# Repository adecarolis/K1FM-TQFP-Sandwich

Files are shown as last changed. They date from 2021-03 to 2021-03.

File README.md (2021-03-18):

# TQFP Sandwich

## A fully open sourced drop-in replacement for the [DL2MAN Sandwich](https://dl2man.de/)

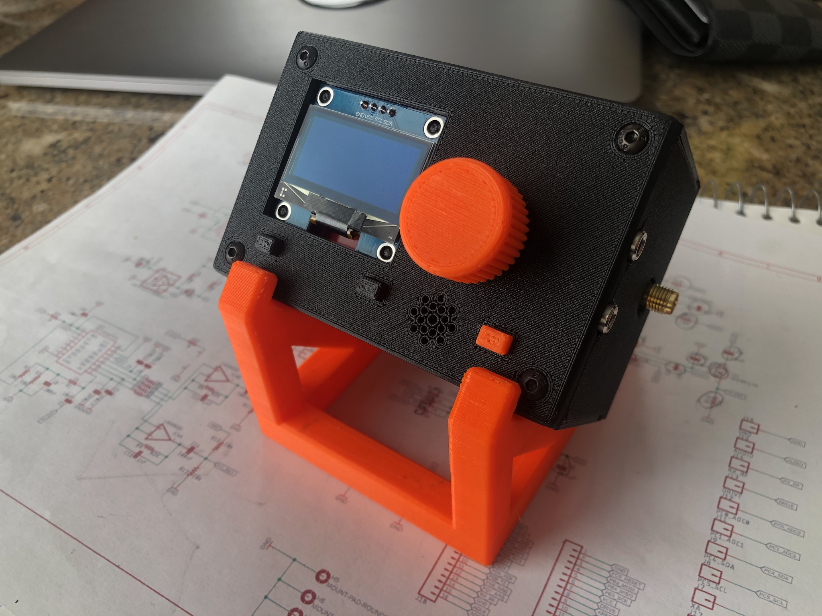
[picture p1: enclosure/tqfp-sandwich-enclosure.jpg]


This sligthly modified version of [Manuel DL2MAN](https://dl2man.de/)'s exceptional project was originally motivated by the need of a proper power connector and a TCXO. Subsequently an SWR meter and a 1.3" oled display were added.

### Boards

#### Main

- ATM328P on TQFP-32 footprint + all SMD components + single side, 2 layers design ($2 per 5 bare PCBs at JLCPCB)
- Available CPL and BOM files for rapid prototyping orders (~$39 for 5 fully assembled PCBs at JLCPCB ***)
- Round barrel jack connector compatible with the FT-817 (1.70mm ID - 4.00mm OD)
- Temperature Controlled Oscillator (TCXO) for absolute frequency precision (alignment no longer necessary)
- Extra 0 ohm resistors / contact pads for easier experimenting and troubleshooting

#### UI

- Accepts both 0.96" and 1.3" OLED displays
- Anti-bounce capacitors allowing for low-cost encoders being used
- Optional GPS receiver + antenna (not yet tested)
- Optional LM386 audio amplifier (not yet tested)

#### RF

- Compatible with DL2MAN REV3 standard RF boards
- Onboard SWR/Wattmeter
- High bands design: 10m, 15m, 20m, 30m, 40m
- SMD design allows for using either a single IRLML2060 or three MMBF170's (caps and toroids need to be matched accordingly)
- SMD Relays (Omron G6KU-2G-Y)

*** Parts not available (or currently not in stock) at LCSC that need to be sourced and installed separately: PJ-18H, Si5351, LM4562MAX, ASTX-H11-27.000MHZ-T, FST3253MTCX

### Testing

 This project is to be considered as experimental. If you are looking for stability and reliabiality, I'd recommend sticking to the original. 

| Board | Number built | Remarks | Issues |
| :---: | :---: | --- | --- |
| Main  | 4 | - No performance differences from the original found yet.<br />- Only tested with OLED displays. | |
|  UI | 5 | - Most 1.3" displays work normally but some require [a software patch](https://groups.io/g/ucx/message/5147?p=,,,20,0,0,0::Created,,reverted,20,2,0,79343439) (this would be the case for all UI boards, not just this particular one). | GPS and audio amplifier (both optional) not yet tested. |
|  RF | 1 | - Uses the REV3 IO Extender configuration with 3x SOT23 mosfets therefore passive components can be dimensioned after BS170/MMBF170's or IRLML2060's.<br />- [The SWR meter software](https://github.com/adecarolis/QCX-SSB/tree/swr-meter) modification currently only works for CW when using the straight key. | So far only tested on 20 meters and 40 meters using 3x BS170 mosfets: good performance on 20 meters, not good on 40. |

### License

Creative Commons 3.0

https://creativecommons.org/licenses/by-sa/3.0/

### Disclaimer

COVERED SOFTWARE IS PROVIDED UNDER THIS LICENSE ON AN "AS IS" BASIS, WITHOUT WARRANTY OF ANY KIND, EITHER EXPRESSED OR IMPLIED, INCLUDING, WITHOUT LIMITATION, WARRANTIES THAT THE COVERED SOFTWARE IS FREE OF DEFECTS, MERCHANTABLE, FIT FOR A PARTICULAR PURPOSE OR NON-INFRINGING. THE ENTIRE RISK AS TO THE QUALITY AND PERFORMANCE OF THE COVERED SOFTWARE IS WITH YOU. SHOULD ANY COVERED SOFTWARE PROVE DEFECTIVE IN ANY RESPECT, YOU (NOT THE INITIAL DEVELOPER OR ANY OTHER CONTRIBUTOR) ASSUME THE COST OF ANY NECESSARY SERVICING, REPAIR OR CORRECTION. THIS DISCLAIMER OF WARRANTY CONSTITUTES AN ESSENTIAL PART OF THIS LICENSE. NO USE OF ANY COVERED SOFTWARE IS AUTHORIZED HEREUNDER EXCEPT UNDER THIS DISCLAIMER.

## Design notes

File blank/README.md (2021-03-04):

Blank TQFP Sandwich boards to be used in new project

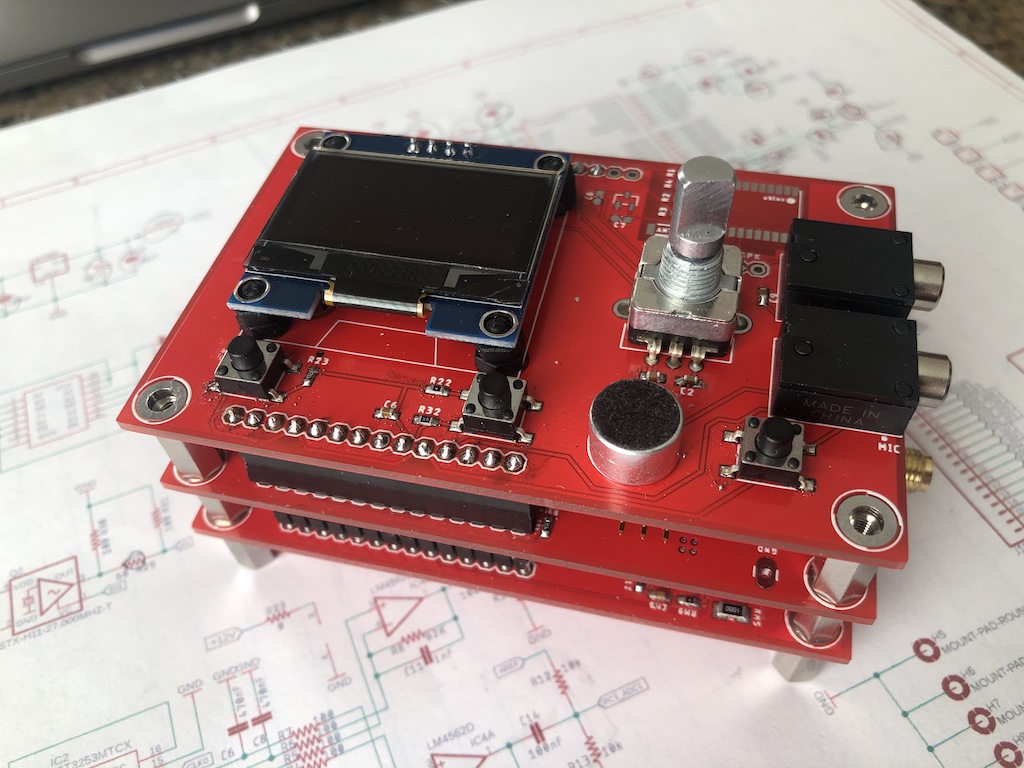
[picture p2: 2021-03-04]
tqfp-sandwich.jpg

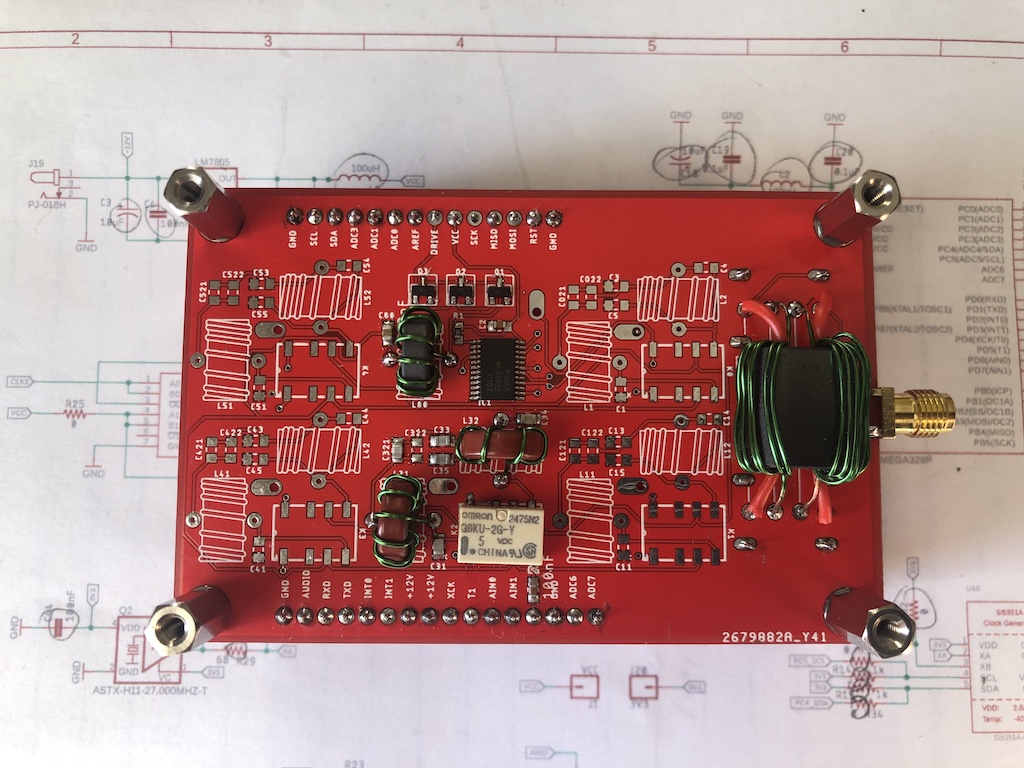
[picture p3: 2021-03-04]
rf/tqfp-sandwich-rf.jpg

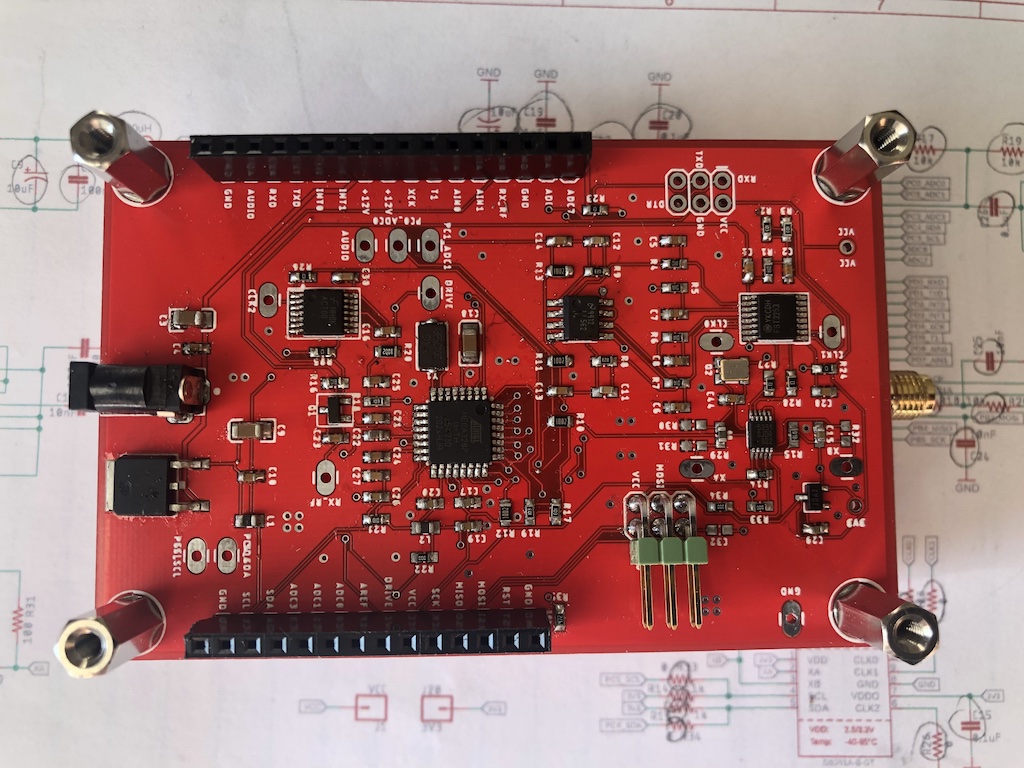
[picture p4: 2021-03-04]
main/tqfp-sandwich-main.jpg

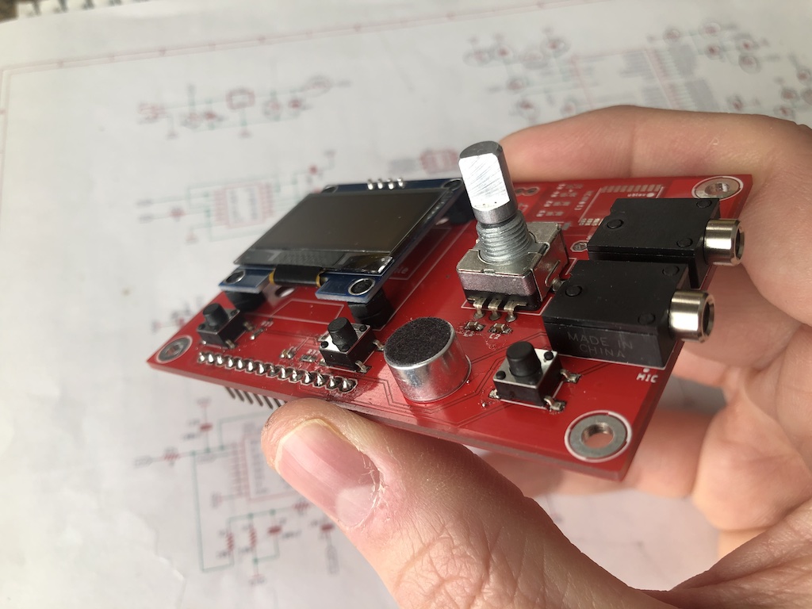
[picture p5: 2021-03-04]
ui/tqfp-sandwich-ui.jpg

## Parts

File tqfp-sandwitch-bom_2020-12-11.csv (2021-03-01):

Qty | Designator | Footprint | Comment | LCSC Part # | Description
5 | C15, C17, C19, C20, C26 | C0603 | 0.1uF | C14663 | 0.1 uF ceramic capacitors
4 | R4, R5, R6, R7 | R0603 | 100 | C22775 | 100 ohm resistors
8 | C2, C4, C10, C13, C14, C28, C30, C44 | C0603 | 10nF | C57112 | 10nF ceramic capacitors
2 | L1, L2 | RESC0603_L |  | C68035 | Generic chip inductor
7 | R2, R3, R17, R18, R19, R20, R21 | R0603 | 10k | C98220 | 10K Resistor
8 | C1, C16, C21, C23, C24, C25, C27, C99 | C0603 | 10nF | C57112 | 0.01uF/10nF/10,000pF ceramic capacitors
1 | C22 | C0603 | 10uF | C19702 | 10uF ceramic capacitors
3 | C3, C9, C18 | EIA3216 | 10uF | C13585 | 10uF capacitors
4 | R1, R14, R15, R16 | R0603 | 1k | C21190 | 1k resistors
2 | C11, C12 | C0603 | 1nF | C1588 | 1nF ceramic capacitors
4 | C5, C6, C7, C8 | C0603 | 470nF | C123513 | 470nF ceramic capacitors
1 | IC3 | SOP65P640X120-14N |  | C133585 | Fairchild Semiconductor 74ACT00MTC, NAND Quad 2 Input NAND, 4.5 5.5 V, 14-Pin TSSOP
1 | Y1 | RESONATOR-SMD-1:1 |  | C112566 | 20MHz Resonator
2 | R8, R9 | R0603 | 82K | C23254 | 82K Resistors
1 | Q2 | 3.2X2.5_KXO-84 |  |  | ASTX-H11-27.000MHZ-T
1 | U1 | TQFP32-08 | ATMEGA328P_TQFP | C14877 | Popular 328P in QFP
1 | IC2 | SOP65P640X110-16N |  | C184615 | IC, Fairchild, FST3253MTCX Fairchild Semiconductor FST3253MTCX, Multiplexer/Demultiplexer Dual 4:1 Multiplexer, 4 5.5 V, 16-Pin TSSOP
1 | IC4 | SOIC-8 |  | C57367 | OP AMP also LM158; LM258; LM2904
1 | U2 | TO-252 | +12v | C21706 | Voltage Regulator
1 | Q1 | SOT96P237X111-3N |  | C130879 | MMBF170 N-Channel MOSFET, 500 mA, 60 V, 3-Pin SOT-23 ON Semiconductor
1 | U10 | MSOP10 |  | C529366 | Si5351A 8kHz-160MHz I2C Clock Generator
1 | R22, R23, R24, R25, R26, R27, R28 | R0603 | 0 | C21189 | 0ohm resistor
1 | D1 | SOT23 |  | C145516 | Diodes
4 | R10, R11, R12, R13 | C0603 | 10K | C39050 | 10K Resistor 0.1%

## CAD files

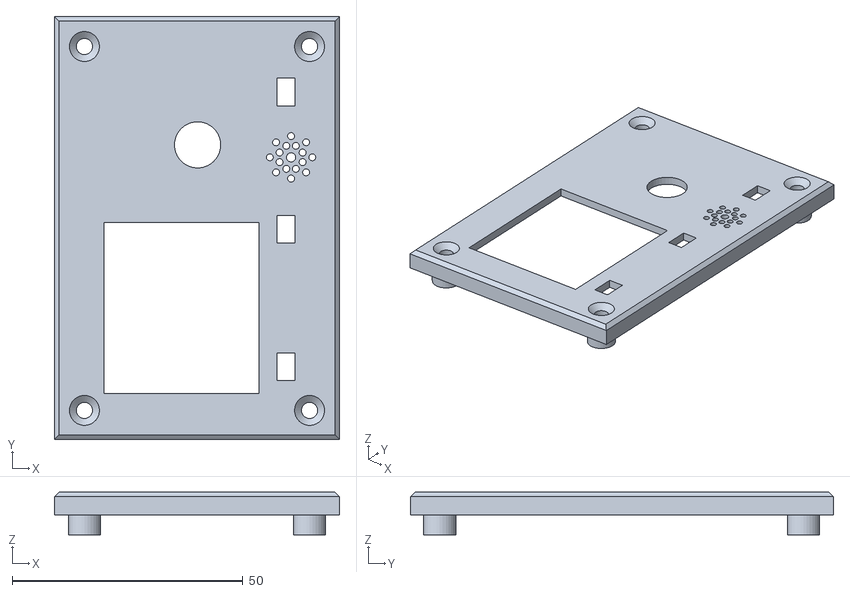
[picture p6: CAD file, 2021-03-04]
enclosure/top.stl
61.8 x 91.6 x 9.30

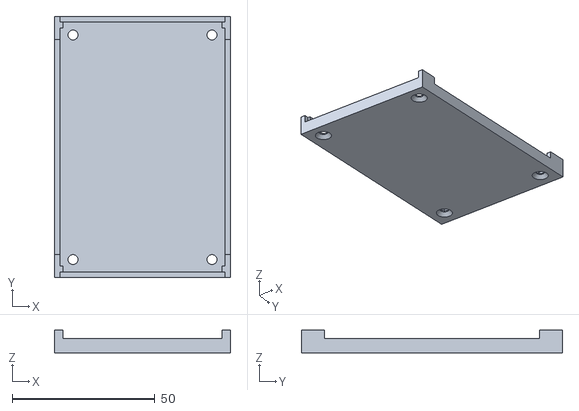
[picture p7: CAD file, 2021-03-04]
enclosure/bottom.stl
61.8 x 91.6 x 8.00

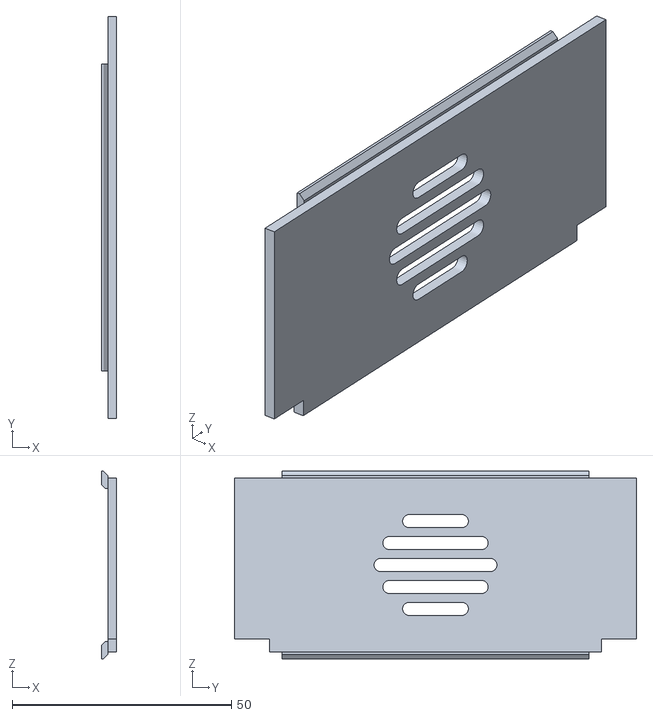
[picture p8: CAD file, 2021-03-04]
enclosure/long-side-open.stl
3.50 x 91.6 x 42.8

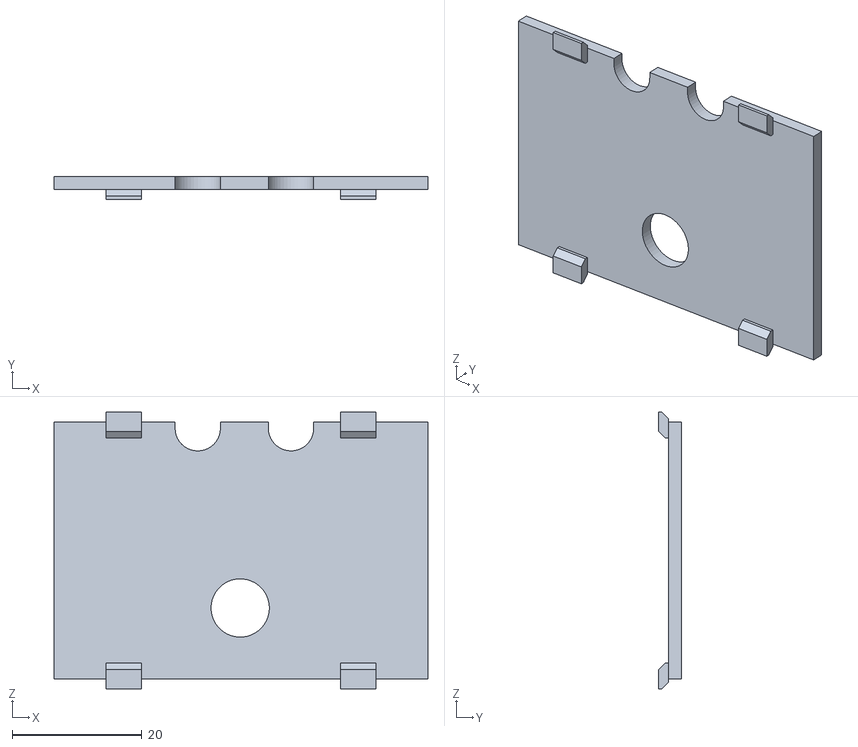
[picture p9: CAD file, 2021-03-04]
enclosure/antenna-side.stl
57.8 x 3.50 x 42.8

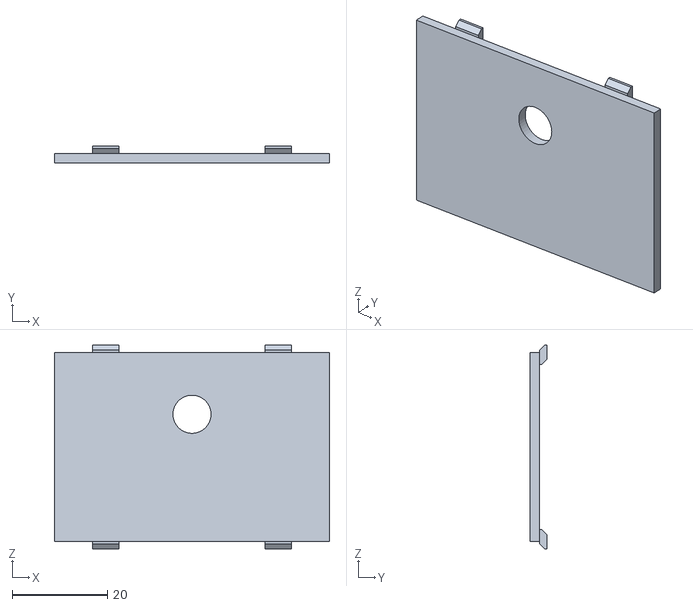
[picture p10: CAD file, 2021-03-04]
enclosure/power-side.stl
57.8 x 3.50 x 42.8

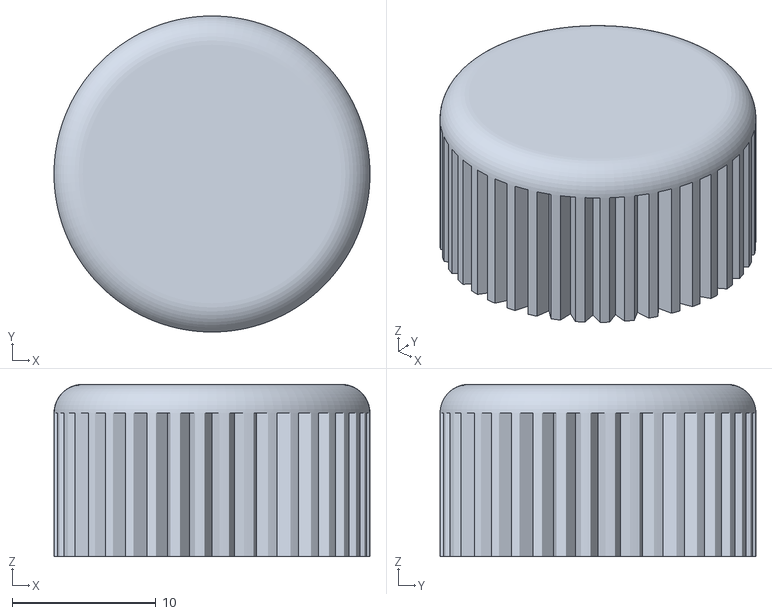
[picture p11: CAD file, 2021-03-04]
enclosure/encoder-knob-PEC11H-4115F-S0020.stl
22.0 x 22.0 x 12.0

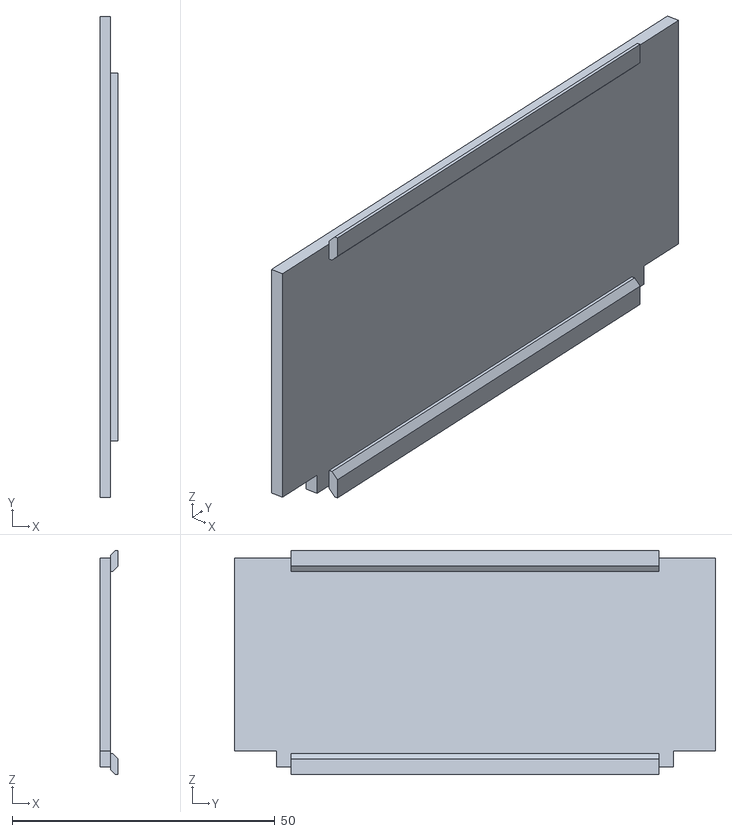
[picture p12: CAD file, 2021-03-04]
enclosure/long-side-closed.stl
3.50 x 91.6 x 42.8

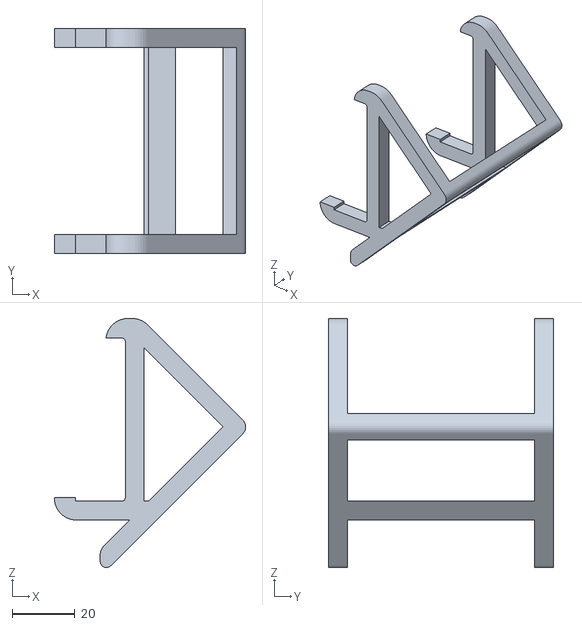
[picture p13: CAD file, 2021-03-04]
enclosure/base.stl
60.9 x 71.6 x 79.2

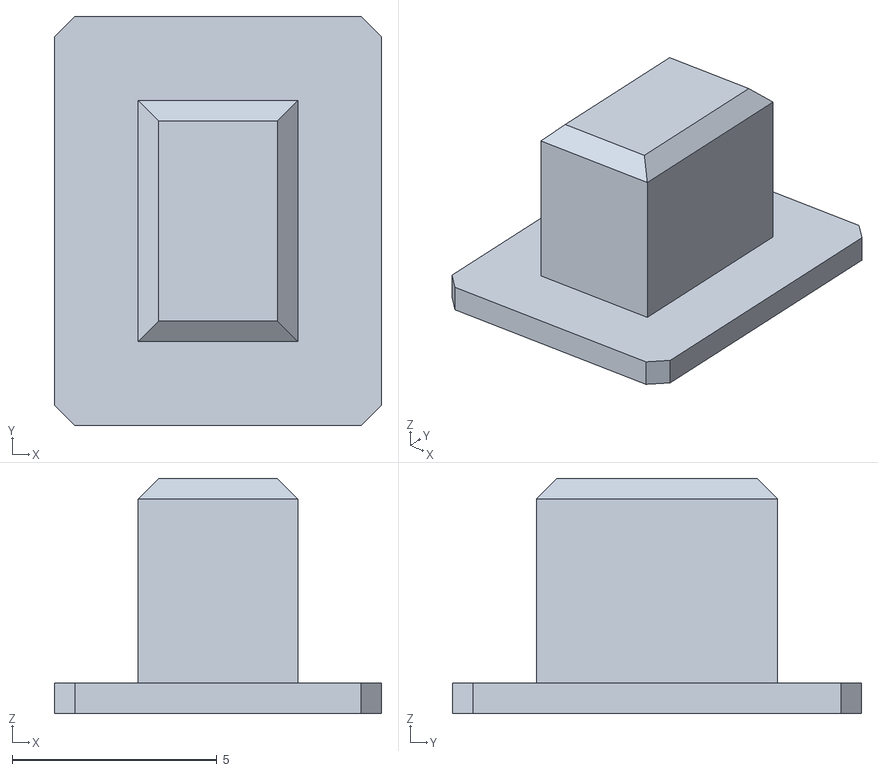
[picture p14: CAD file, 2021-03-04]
enclosure/button.stl
8.00 x 10.0 x 5.75

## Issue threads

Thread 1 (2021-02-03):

CAD files available

scottlbaker, 2021-02-03:
Are the DXP schematic and layout CAD files available?

Thanks

adecarolis, 2021-03-01:
Scott,
the source drawings are now available
Alain

Closed 2021-03-01.

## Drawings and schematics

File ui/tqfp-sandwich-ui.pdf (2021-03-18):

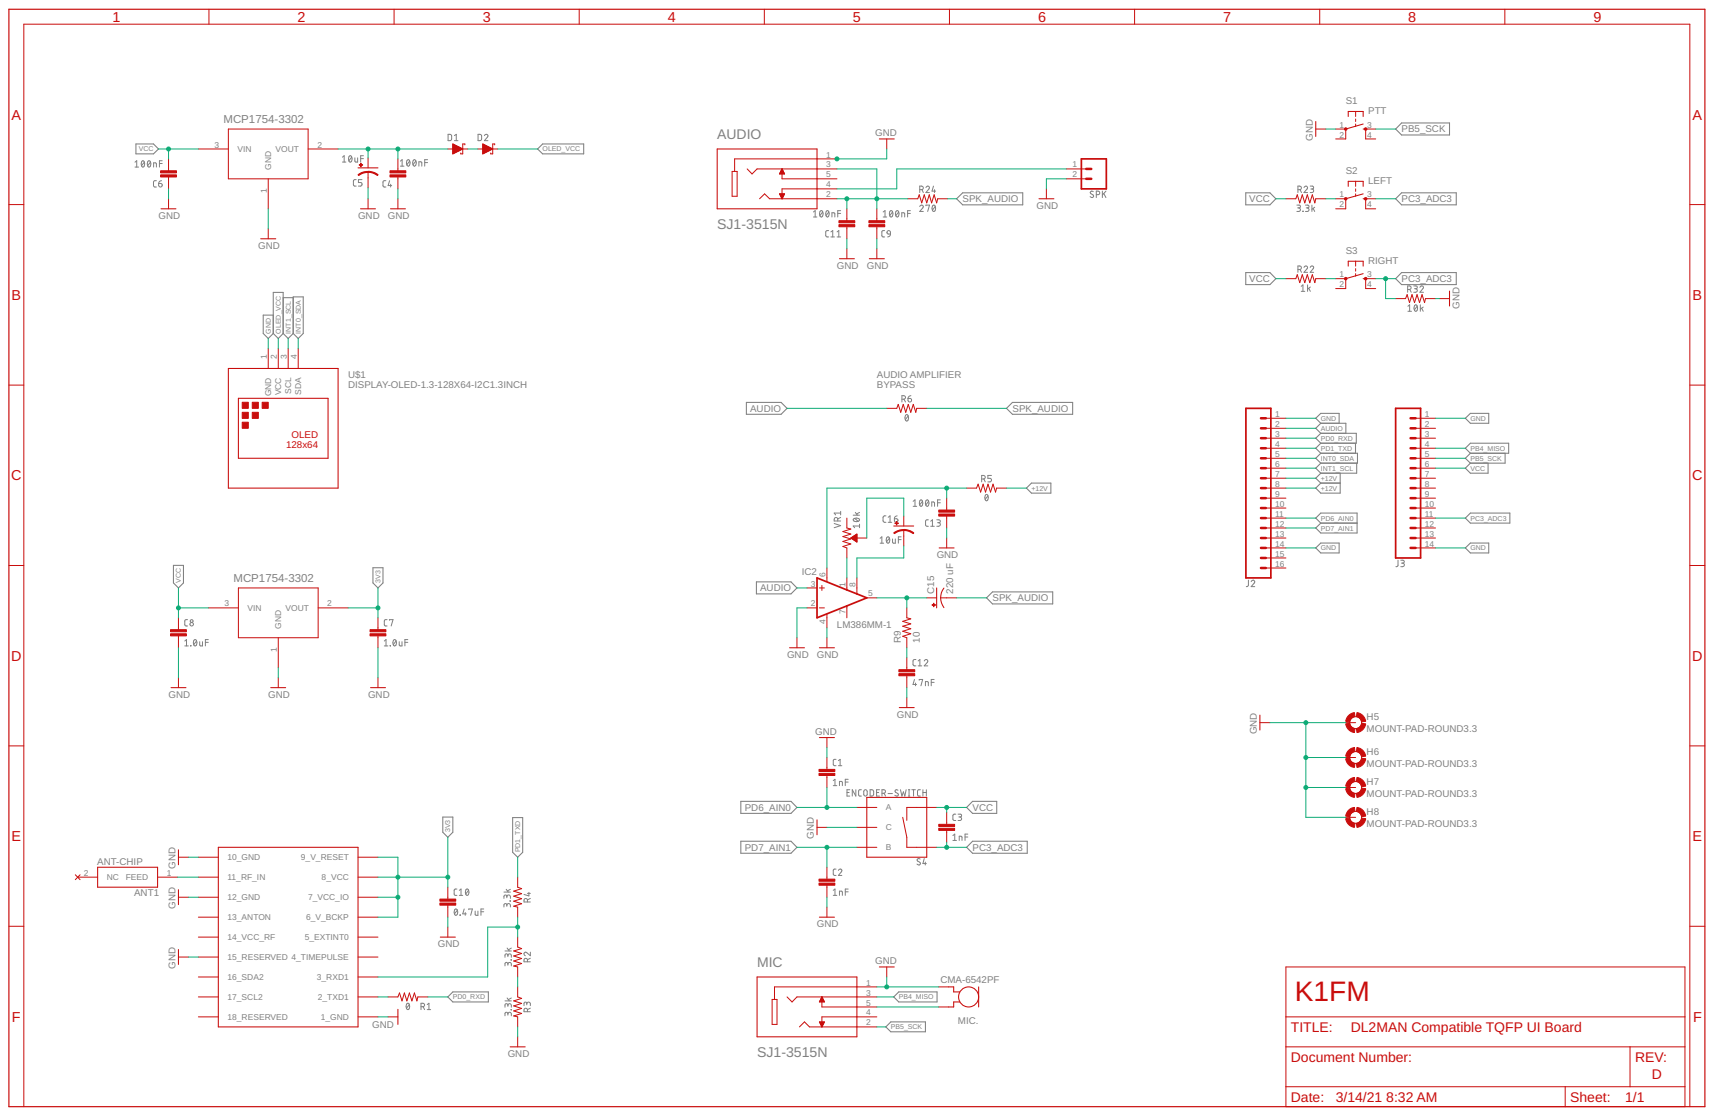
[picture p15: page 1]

GND MOUNT-PAD-ROUND3.3 MOUNT-PAD-ROUND3.3 MOUNT-PAD-ROUND3.3 MOUNT-PAD-ROUND3.3 LEFT PTT RIGHT GND GND GND GND GND CMA-6542PF DISPLAY-OLED-1.3-128X64-I2C1.3INCH GND GND GND GNDGND ANT1 GND GND GND SJ1-3515N SJ1-3515N GND GND GND GND GND GND MCP1754-3302 GND GND MCP1754-3302 GND LM386MM-1 10 220 uF GND GND GND GND GND AUDIO AMPLIFIER BYPASS 1234567891011121314 H5 H6 H7 H8 1 3 2 4 S2 1 3 2 4 S1 1 3 2 4 S3 BCA MIC. GND 1 VCC 2 SCL 3 SDA 4 U$1 10_GND 11_RF_IN 12_GND 13_ANTON 14_VCC_RF 15_RESERVED 16_SDA2 17_SCL2 18_RESERVED 9_V_RESET 8_VCC 7_VCC_IO 6_V_BCKP 5_EXTINT0 4_TIMEPULSE 3_RXD1 2_TXD1 1_GND FEED 1 NC 2 ANT-CHIP 13245 AUDIO 13245 MIC 12345678910111213141516 GND 1 VOUT 2 VIN 3 GND 1 VOUT 2 VIN 3 1 23 8 5 6 4 7 IC2 R9 C15 12 GND GND GND GND GND AUDIO AUDIO AUDIO PC3_ADC3 PC3_ADC3 PC3_ADC3 PC3_ADC3 PD6_AIN0 PD6_AIN0 PD7_AIN1 PD7_AIN1 VCC VCC VCC VCC VCC VCC PB4_MISO PB4_MISO PB5_SCK PB5_SCK PB5_SCK PD0_RXD PD0_RXD PD1_TXD PD1_TXD 3V3 3V3 INT1_SCL INT1_SCL INT0_SDA INT0_SDA OLED_VCC OLED_VCC SPK_AUDIO SPK_AUDIOSPK_AUDIO +12V +12V +12V DL2MAN Compatible TQFP UI Board D K1FM ABCDEF ABCDEF 1 2 3 4 5 6 7 8 9 Date: Sheet: REV: TITLE: Document Number: 3/14/21 8:32 AM 1/1 128x64 OLED

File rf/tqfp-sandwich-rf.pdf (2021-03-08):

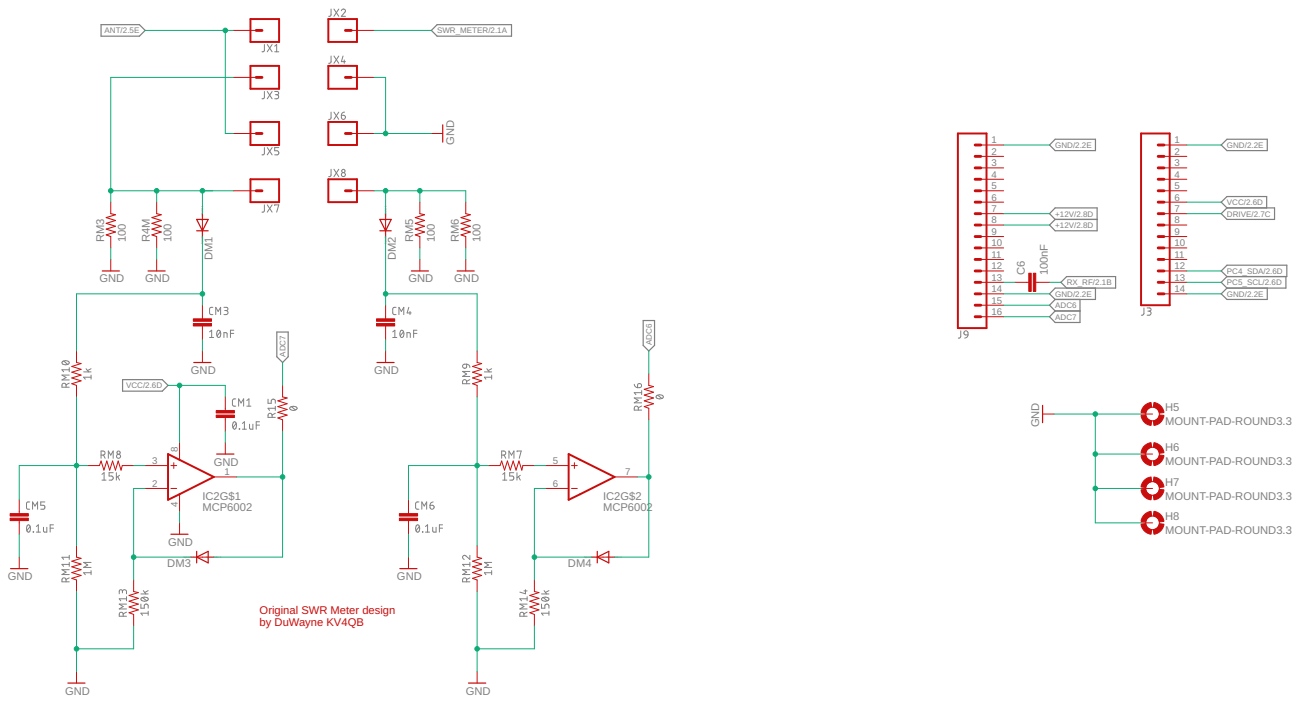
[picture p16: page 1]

MOUNT-PAD-ROUND3.3 MOUNT-PAD-ROUND3.3

Original SWR Meter design
by DuWayne KV4QB

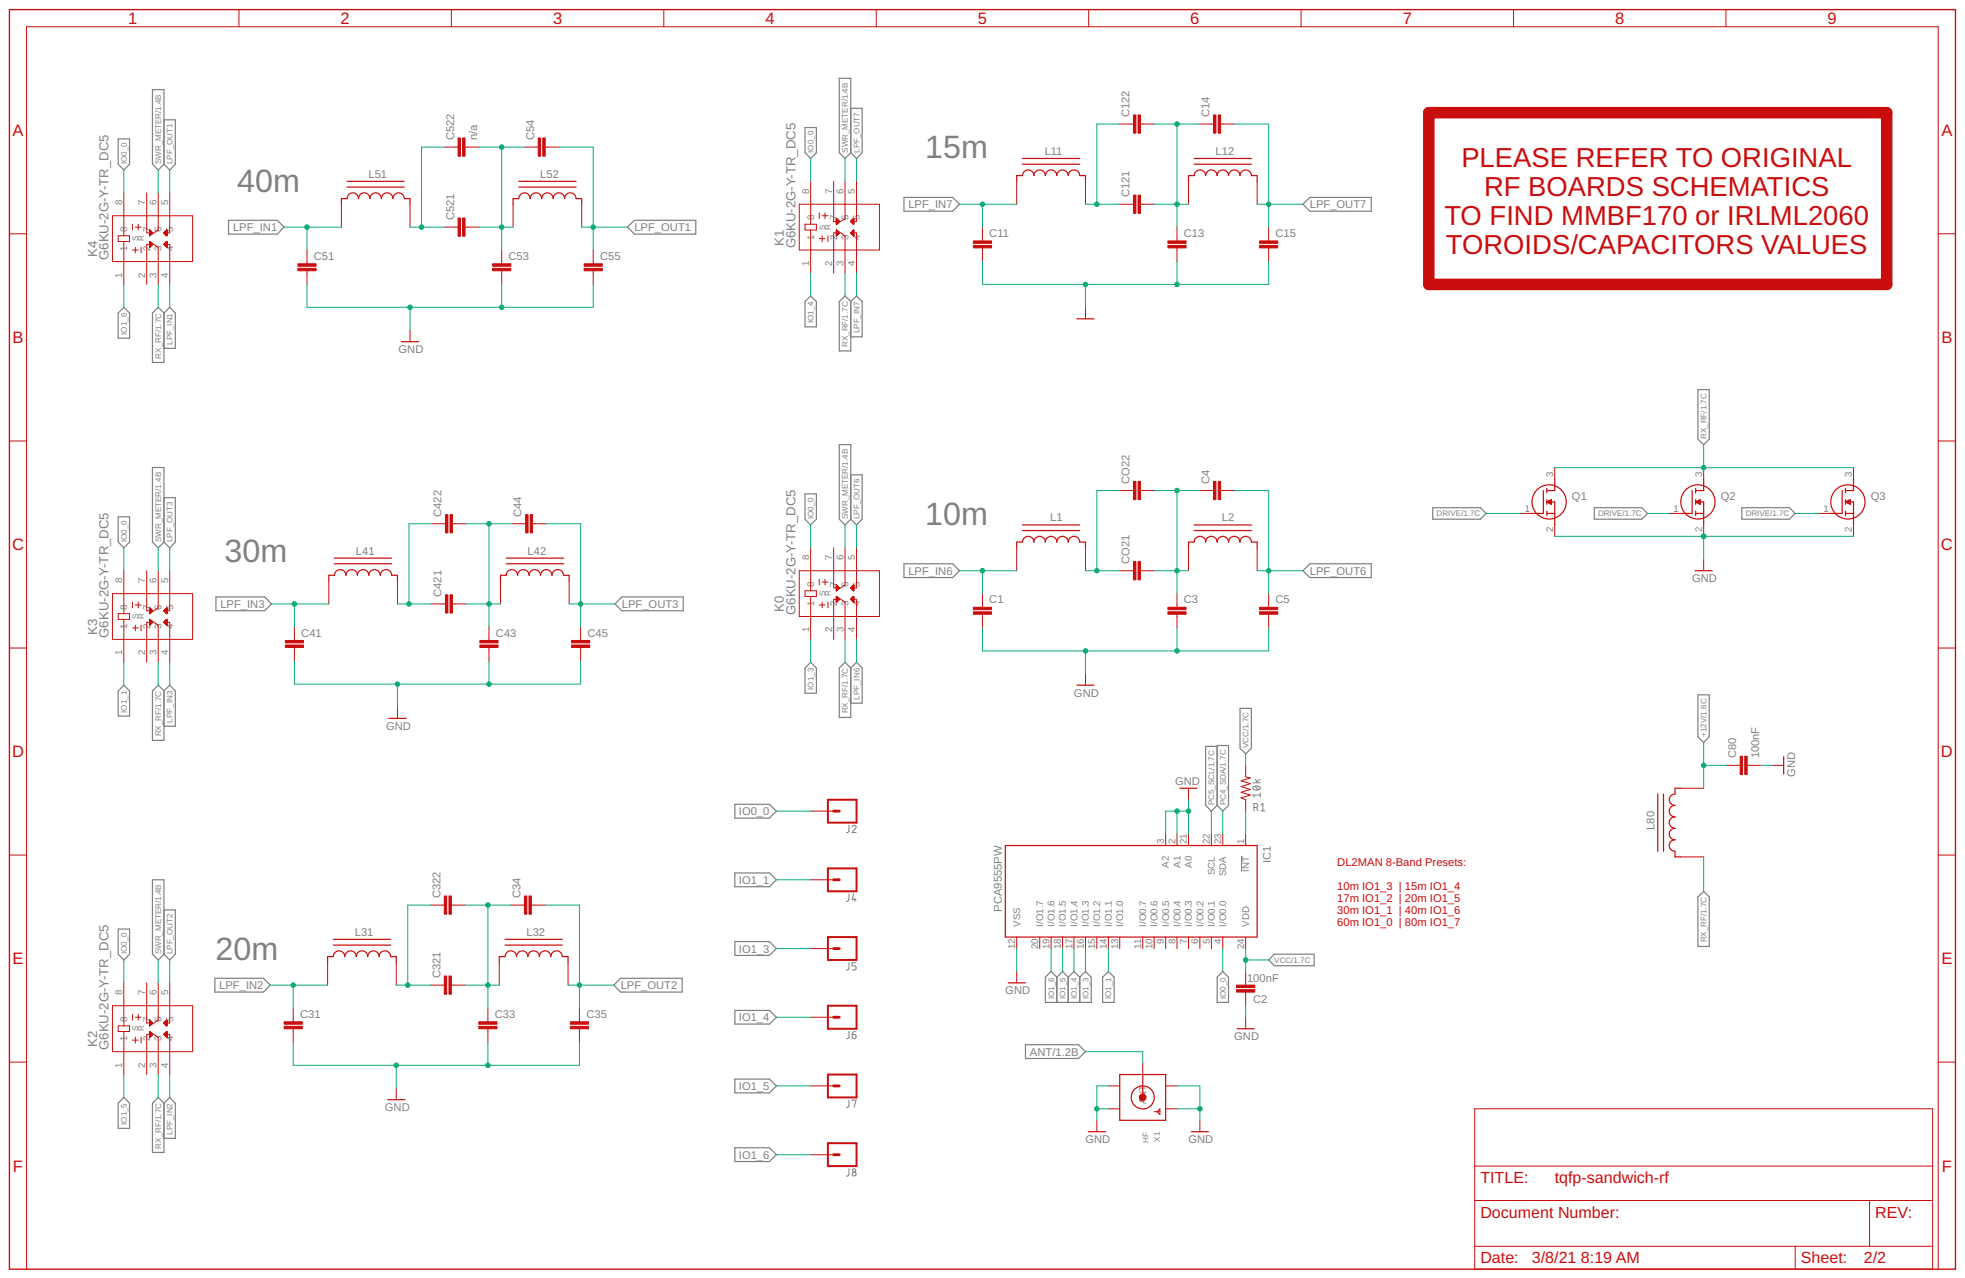
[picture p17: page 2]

PLEASE REFER TO ORIGINAL
RF BOARDS SCHEMATICS
TO FIND MMBF170 or IRLML2060
TOROIDS/CAPACITORS VALUES

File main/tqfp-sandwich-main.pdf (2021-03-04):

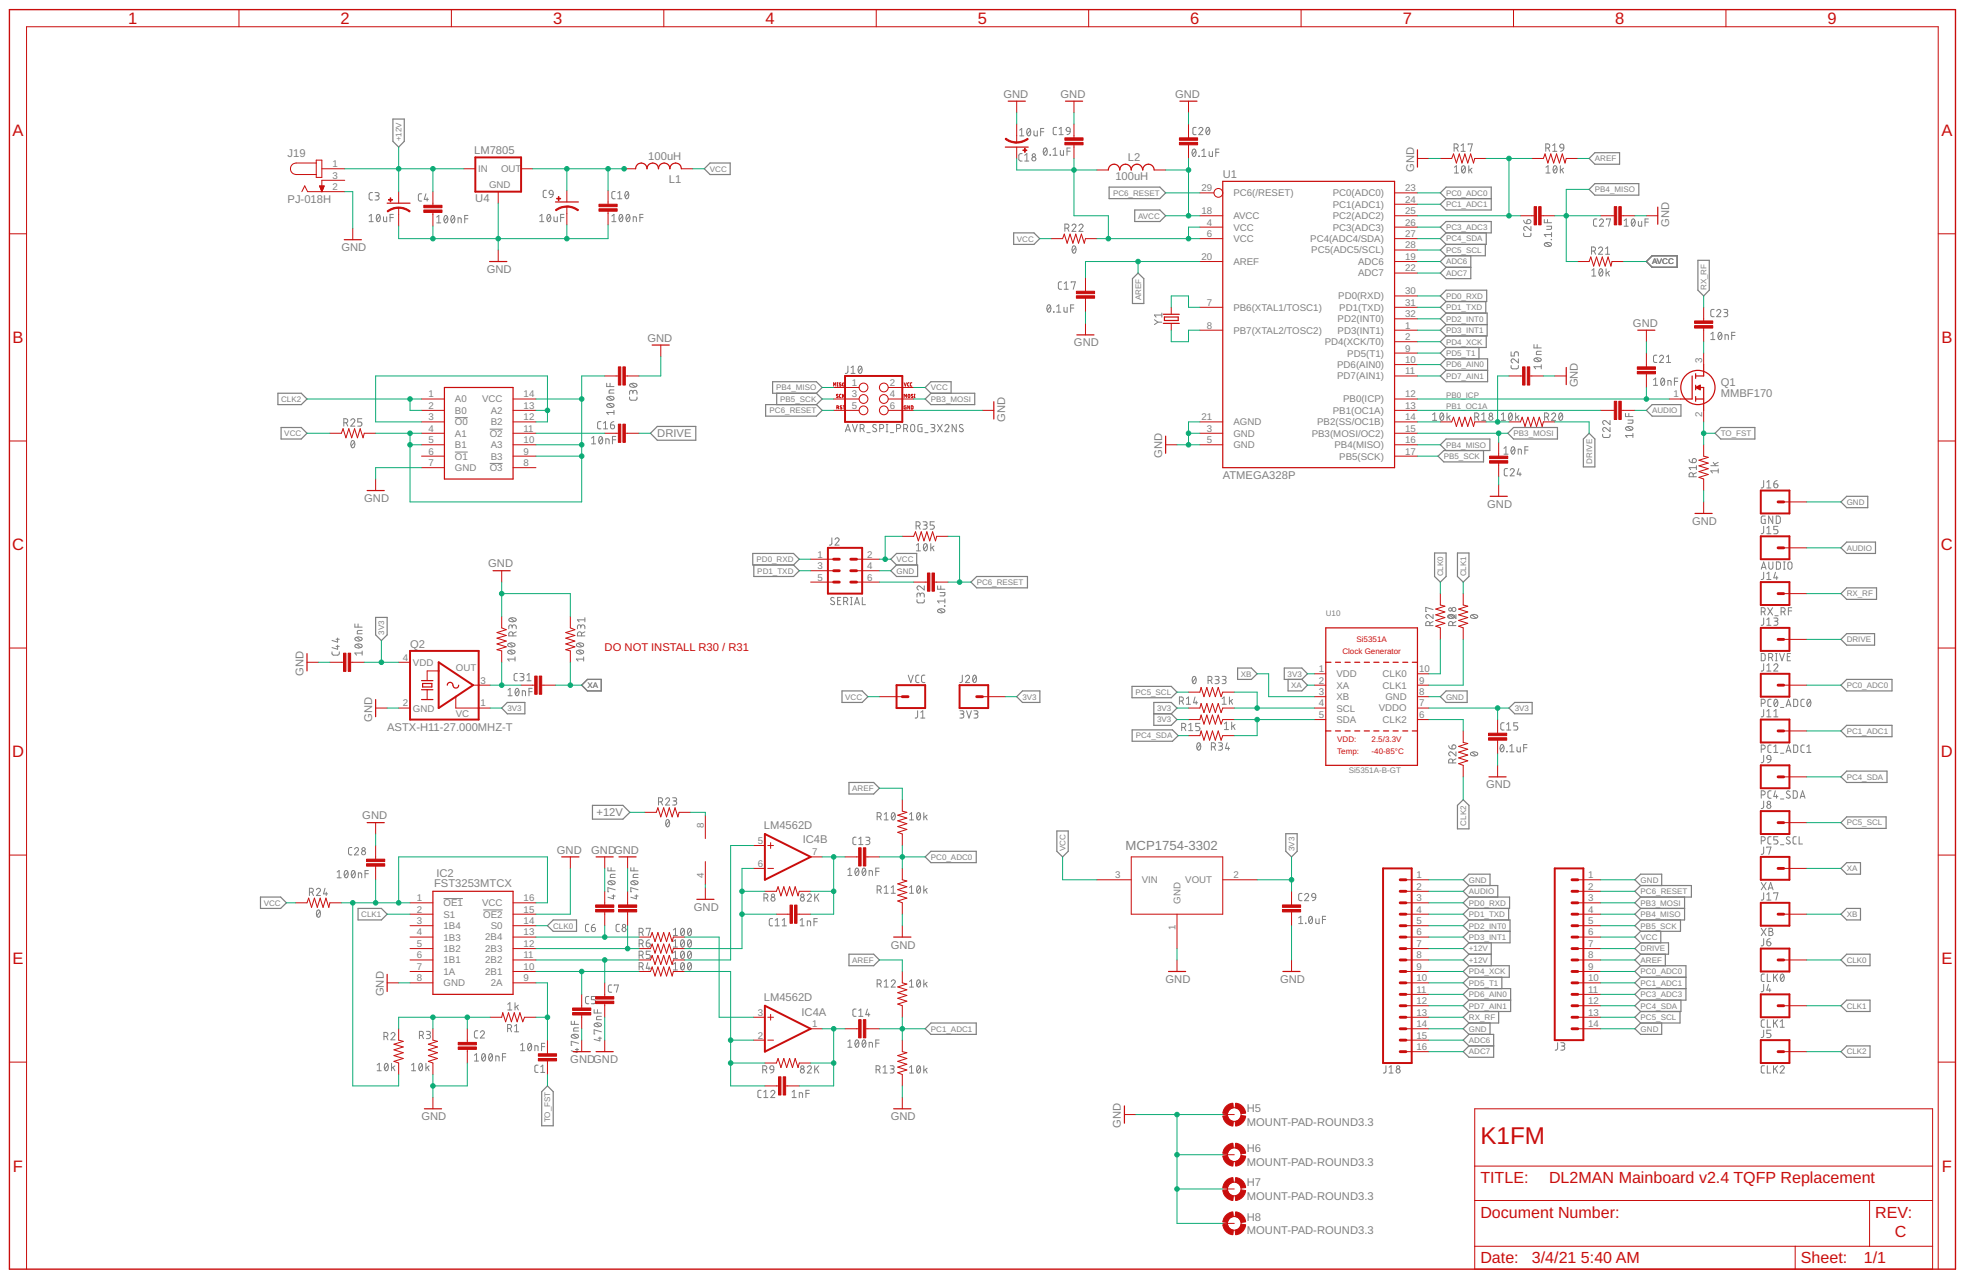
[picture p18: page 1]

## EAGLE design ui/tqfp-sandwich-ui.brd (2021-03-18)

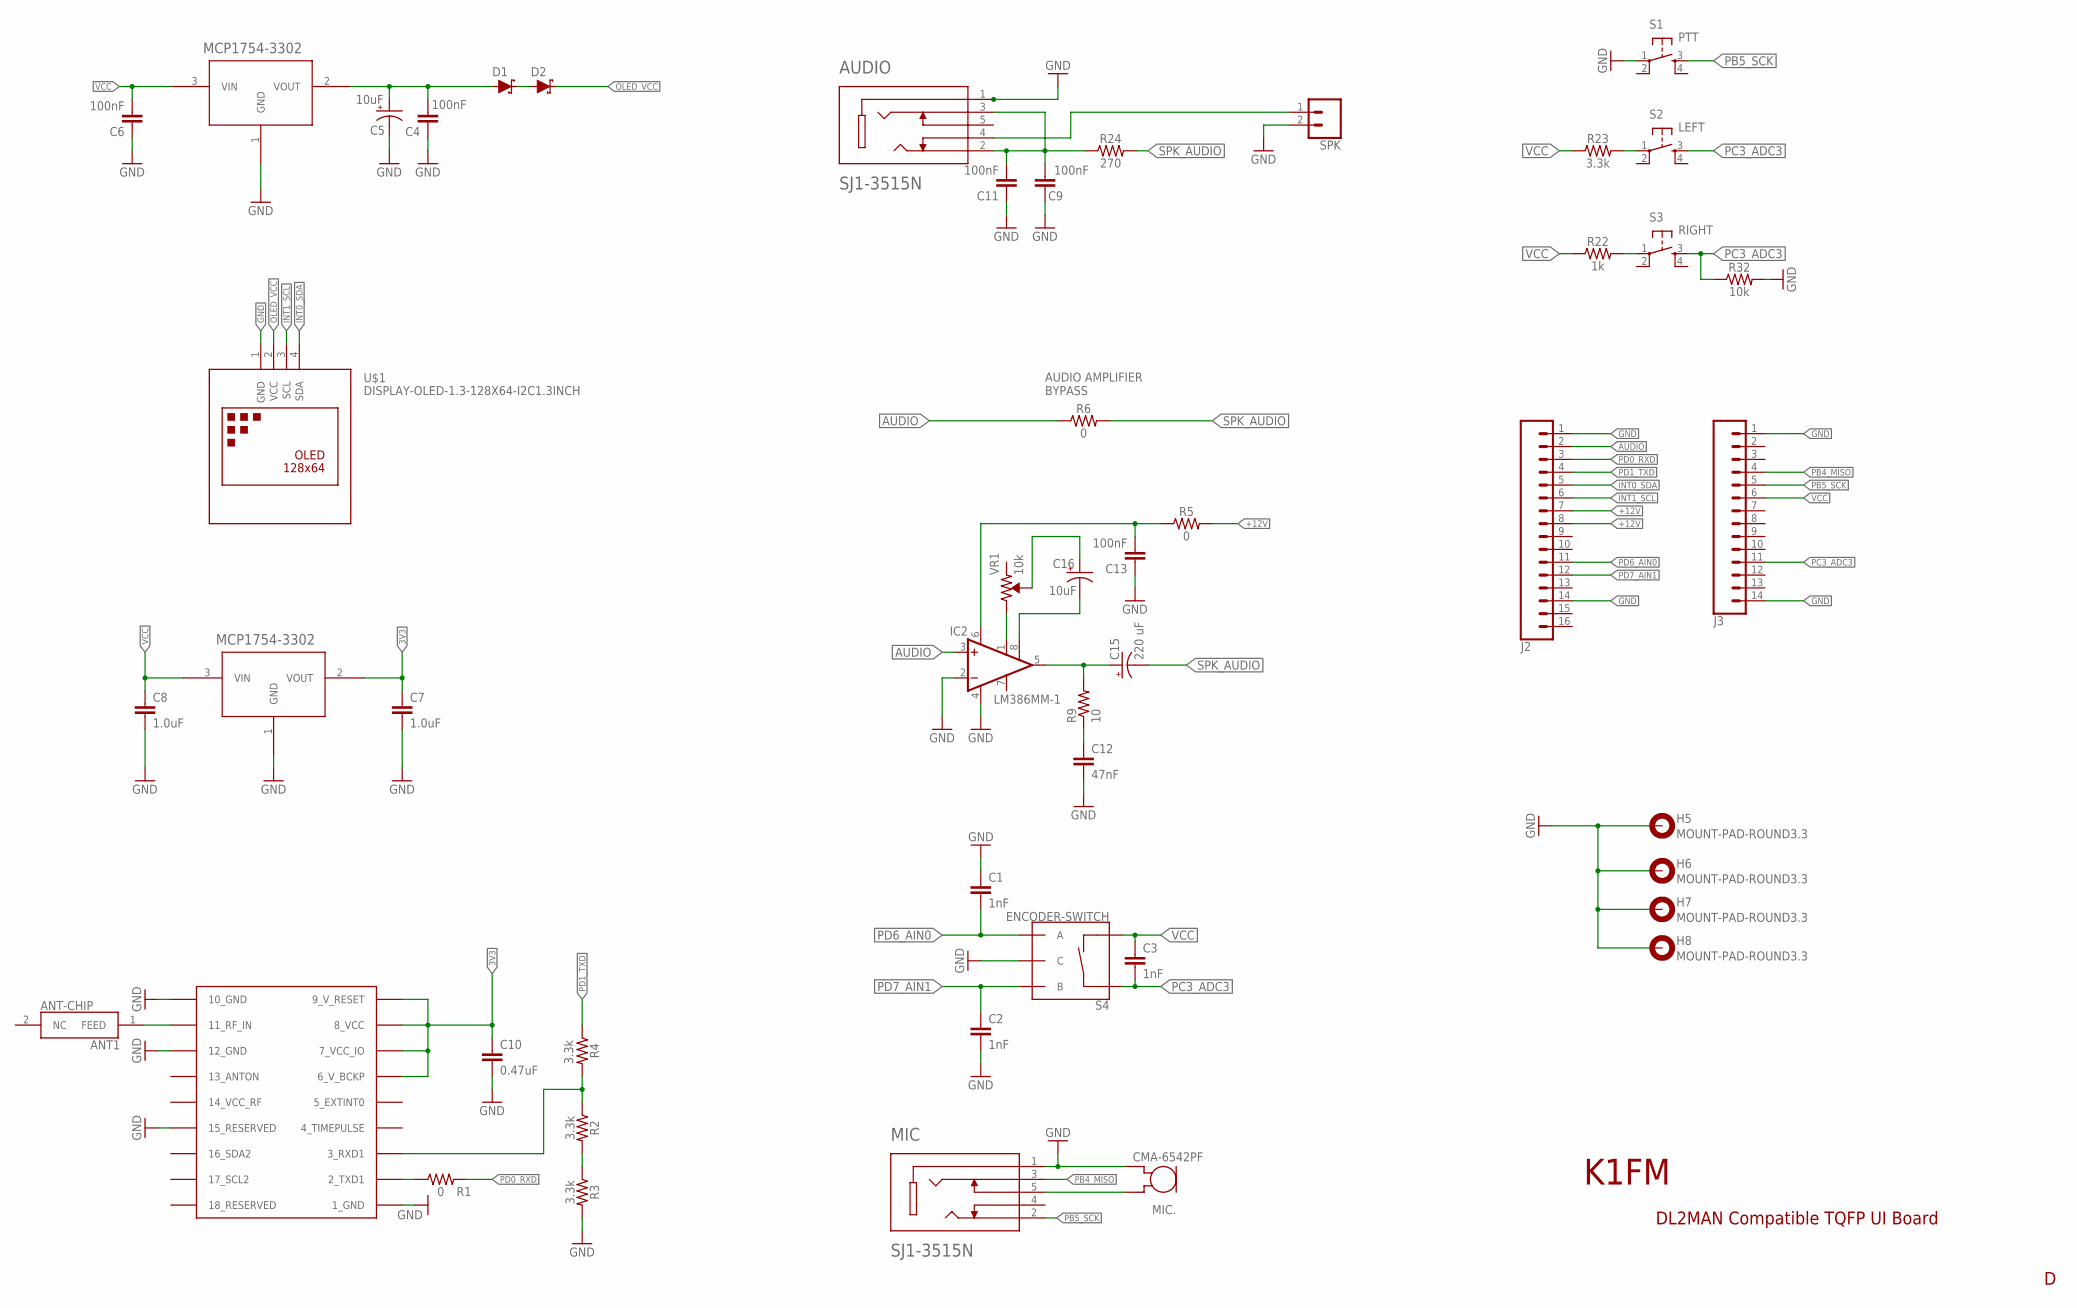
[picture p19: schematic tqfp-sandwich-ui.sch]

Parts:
ANT-CHIP: ANT1; 1575AT43A0040E
AUDIO: SJ1-3515N; CUI_SJ1-3515N
C1, C2, C3: 1nF; 0603
C4, C6, C9, C11, C13: 100nF; 0603
C5, C16: 10uF; EIA3216
C7, C8: 1.0uF; 0603
C10: 0.47uF; 0603
C12: 47nF; 0603
C15: 220 uF; PANASONIC_C
D1, D2: 1A/23V/620mV; SOD-323
GPS1: UBLOX_MAX
H5, H6, H7, H8: MOUNT-PAD-ROUND3.3; 3,3-PAD
IC2: LM386MM-1; MMSOP08
J2: CONN_16; 1X16
J3: CONN_14; 1X14
MIC: SJ1-3515N; CUI_SJ1-3515N
MIC.: CMA-6542PF; CUI_CMA-6542PF
R1, R5, R6: 0; 0603
R2, R3, R4, R23: 3.3k; 0603
R9: 10; 0603
R22: 1k; 0603
R24: 270; 0603
R32: 10k; 0603
S1: PTT; DTSM-6
S2: LEFT; DTSM-6
S3: RIGHT; DTSM-6
S4: ENCODER-SWITCH; ROTARY_ENC_PLAIN
SPK: CONN_02; 1X02
U1, U3: MCP1754X-XXXXX/C; SOT-23A_MC
U$1: DISPLAY-OLED-1.3-128X64-I2C1.3INCH; DISPLAY-OLED-1.3-128X64-I2C
VR1: 10k; TRIMPOT-SMD-TC33X

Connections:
3V3: C7.1, C10.1, GPS1.6_V_BCKP, GPS1.7_VCC_IO, GPS1.8_VCC, GPS1.9_V_RESET, U3.2 (VOUT)
+12V: J2.7, J2.8, R5.2
AUDIO: IC2.3 (+IN), J2.2, R6.1
GND: AUDIO.1, C1.1, C2.2, C4.1, C5.-, C6.1, C7.2, C8.2, C9.1, C10.2, C11.1, C12.2, C13.1, GPS1.1_GND, GPS1.10_GND, GPS1.12_GND, GPS1.15_RESERVED, H5.B3,3, H6.B3,3, H7.B3,3, H8.B3,3, IC2.2 (-IN), IC2.4 (GND), J2.1, J2.14, J3.1, J3.14, MIC.1, MIC..GND, R3.2, R32.2, S1.1, S4.C, SPK.2, U1.1 (GND), U3.1 (GND), U$1.1 (GND)
INT0_SDA: J2.5, U$1.4 (SDA)
INT1_SCL: J2.6, U$1.3 (SCL)
unnamed: GPS1.2_TXD1, R1.1
unnamed: MIC.5, MIC..OUT
unnamed: GPS1.3_RXD1, R2.1, R4.2
unnamed: R23.2, S2.1
unnamed: R2.2, R3.1
unnamed: ANT-CHIP.1 (FEED), GPS1.11_RF_IN
unnamed: D1.C, D2.A
unnamed: C4.2, C5.+, D1.A, U1.2 (VOUT)
unnamed: C12.1, R9.1
unnamed: AUDIO.4, SPK.1
unnamed: C15.+, IC2.5 (OUT), R9.2
unnamed: IC2.1 (GAIN), VR1.1 (CW)
unnamed: C16.+, VR1.2 (WIPER)
unnamed: C16.-, IC2.8 (GAIN)
unnamed: C13.2, IC2.6 (VS), R5.1
unnamed: R22.2, S3.1
unnamed: AUDIO.2, AUDIO.3, C9.2, C11.2, R24.1
OLED_VCC: D2.C, U$1.2 (VCC)
PB4_MISO: J3.4, MIC.3
PB5_SCK: J3.5, MIC.2, S1.3
PC3_ADC3: C3.2, J3.11, R32.1, S2.3, S3.3, S4.SW+
PD0_RXD: J2.3, R1.2
PD1_TXD: J2.4, R4.1
PD6_AIN0: C1.2, J2.11, S4.A
PD7_AIN1: C2.1, J2.12, S4.B
SPK_AUDIO: C15.-, R6.2, R24.2
VCC: C3.1, C6.2, C8.1, J3.6, R22.1, R23.1, S4.SW-, U1.3 (VIN), U3.3 (VIN)

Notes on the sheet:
DL2MAN Compatible TQFP UI Board
K1FM
AUDIO AMPLIFIER BYPASS

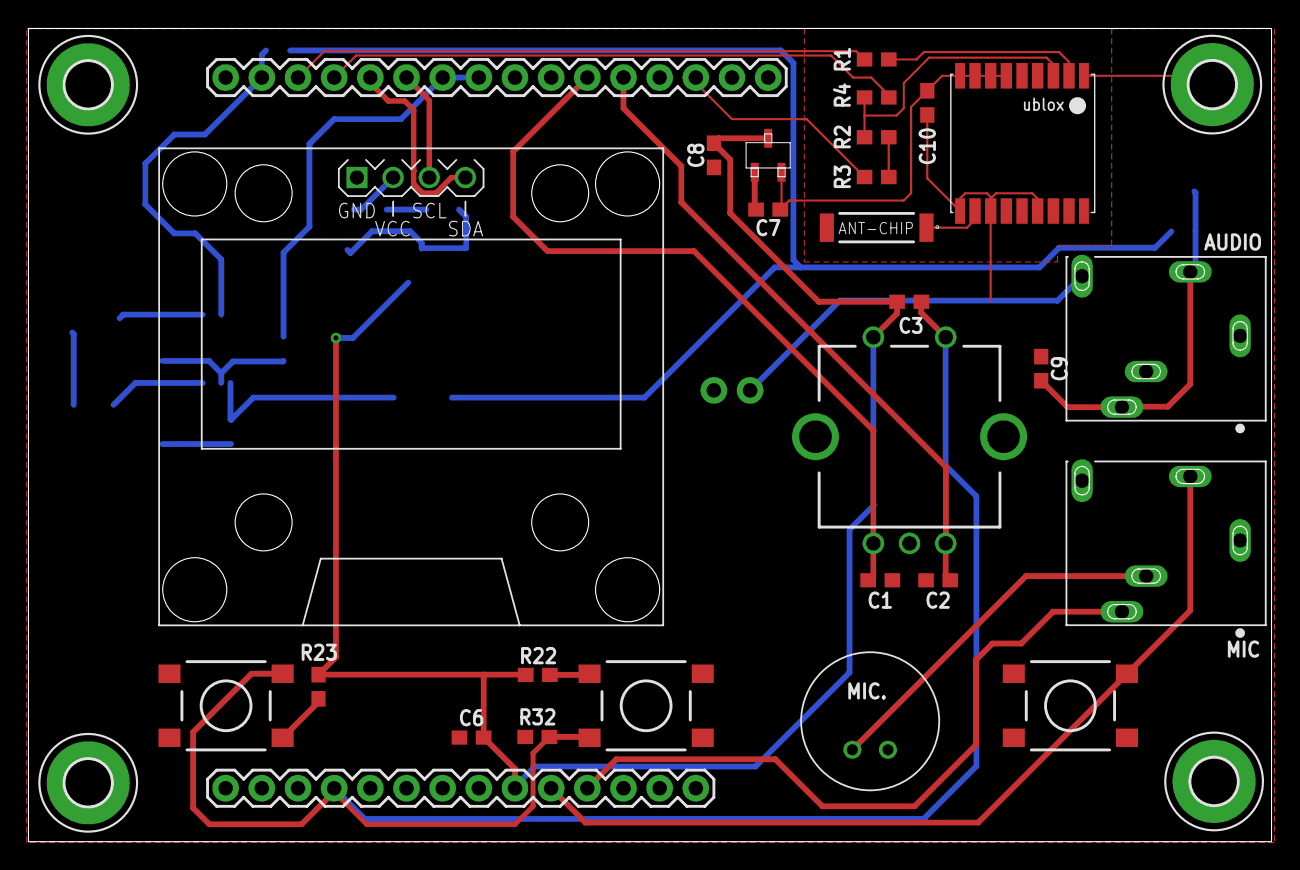
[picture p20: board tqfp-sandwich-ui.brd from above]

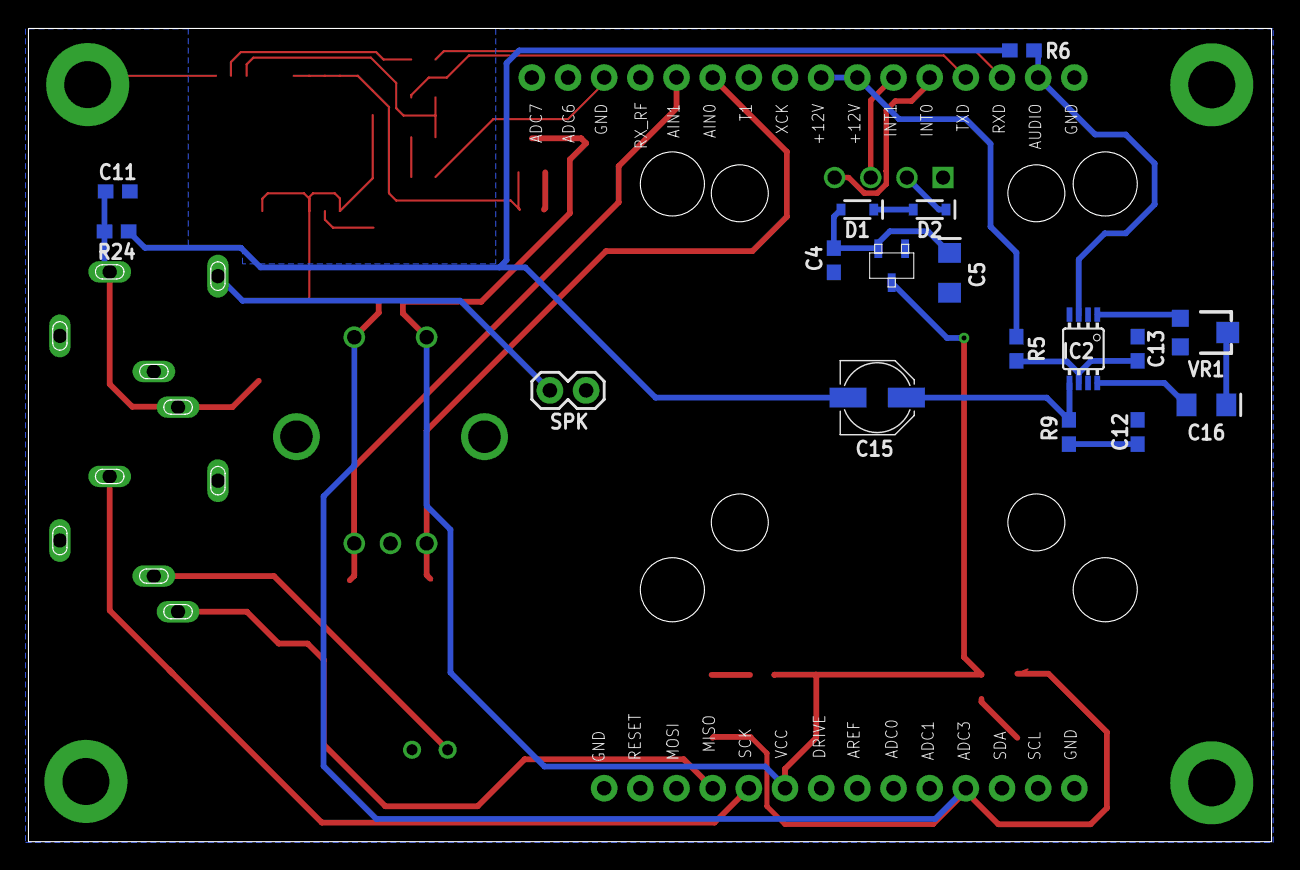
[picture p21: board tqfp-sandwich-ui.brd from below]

Board: 2 copper layers, 87.3 x 57.1 mm, 49 parts (17 on the bottom side), 33 nets.

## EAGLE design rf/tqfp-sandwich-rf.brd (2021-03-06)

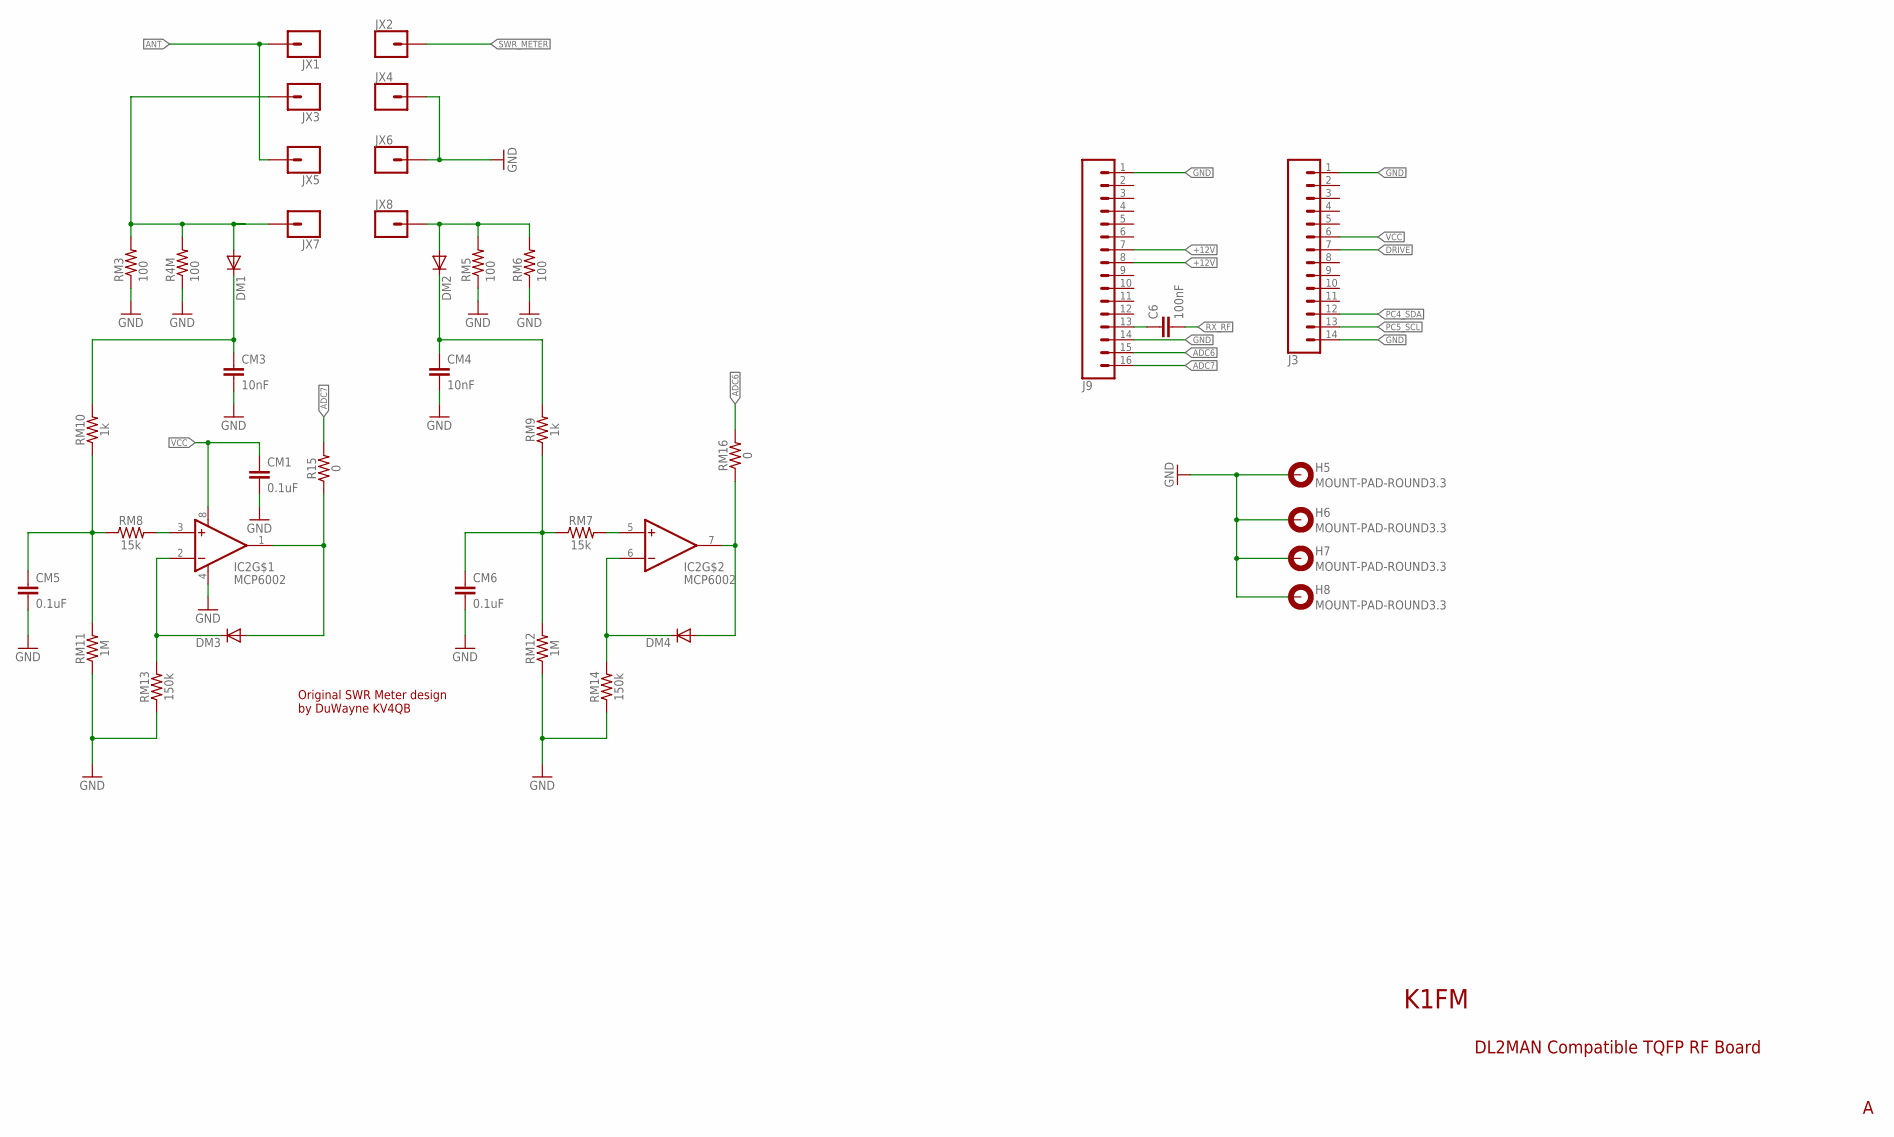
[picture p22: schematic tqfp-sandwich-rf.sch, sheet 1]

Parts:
C6: 100nF; RESC0805_L
CM1, CM5, CM6: 0.1uF; 0603
CM3, CM4: 10nF; 0603
DM1, DM2, DM3, DM4: 1N60P; DO35-10
H5, H6, H7, H8: MOUNT-PAD-ROUND3.3; 3,3-PAD
IC2: MCP6002; SOIC8
J3: CONN_14; 1X14
J9: CONN_16; 1X16
JX1, JX2, JX3, JX4, JX5, JX6, JX7, JX8: CONN_01; 1X01
R4M: 100; M1206
R15: 0; 0603
RM3, RM5, RM6: 100; M1206
RM7, RM8: 15k; 0603
RM9, RM10: 1k; 0603
RM11, RM12: 1M; 0603
RM13, RM14: 150k; 0603
RM16: 0; 0603

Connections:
+12V: J9.7, J9.8; also elsewhere on the board
ADC6: J9.15, RM16.2
ADC7: J9.16, R15.2
ANT: JX1.1, JX5.1; also elsewhere on the board
DRIVE: J3.7; also elsewhere on the board
GND: CM1.2, CM3.2, CM4.2, CM5.2, CM6.2, H5.B3,3, H6.B3,3, H7.B3,3, H8.B3,3, IC2.4 (V-), J3.1, J3.14, J9.1, J9.14, JX4.1, JX6.1, R4M.1, RM3.1, RM5.1, RM6.1, RM11.1, RM12.1, RM13.1, RM14.1; also elsewhere on the board
unnamed: DM3.A, IC2.1 (OUT), R15.1
unnamed: DM4.A, IC2.7 (OUT), RM16.1
unnamed: C6.1, J9.13
unnamed: DM1.A, JX3.1, JX7.1, R4M.2, RM3.2
unnamed: DM2.A, JX8.1, RM5.2, RM6.2
unnamed: CM3.1, DM1.C, RM10.2
unnamed: CM4.1, DM2.C, RM9.2
unnamed: DM3.C, IC2.2 (-IN), RM13.2
unnamed: DM4.C, IC2.6 (-IN), RM14.2
unnamed: IC2.3 (+IN), RM8.2
unnamed: IC2.5 (+IN), RM7.2
unnamed: CM6.1, RM7.1, RM9.1, RM12.2
unnamed: CM5.1, RM8.1, RM10.1, RM11.2
PC4_SDA: J3.12; also elsewhere on the board
PC5_SCL: J3.13; also elsewhere on the board
RX_RF: C6.2; also elsewhere on the board
SWR_METER: JX2.1; also elsewhere on the board
VCC: CM1.1, IC2.8 (V+), J3.6; also elsewhere on the board

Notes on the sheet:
DL2MAN Compatible TQFP RF Board
K1FM
Original SWR Meter design by DuWayne KV4QB

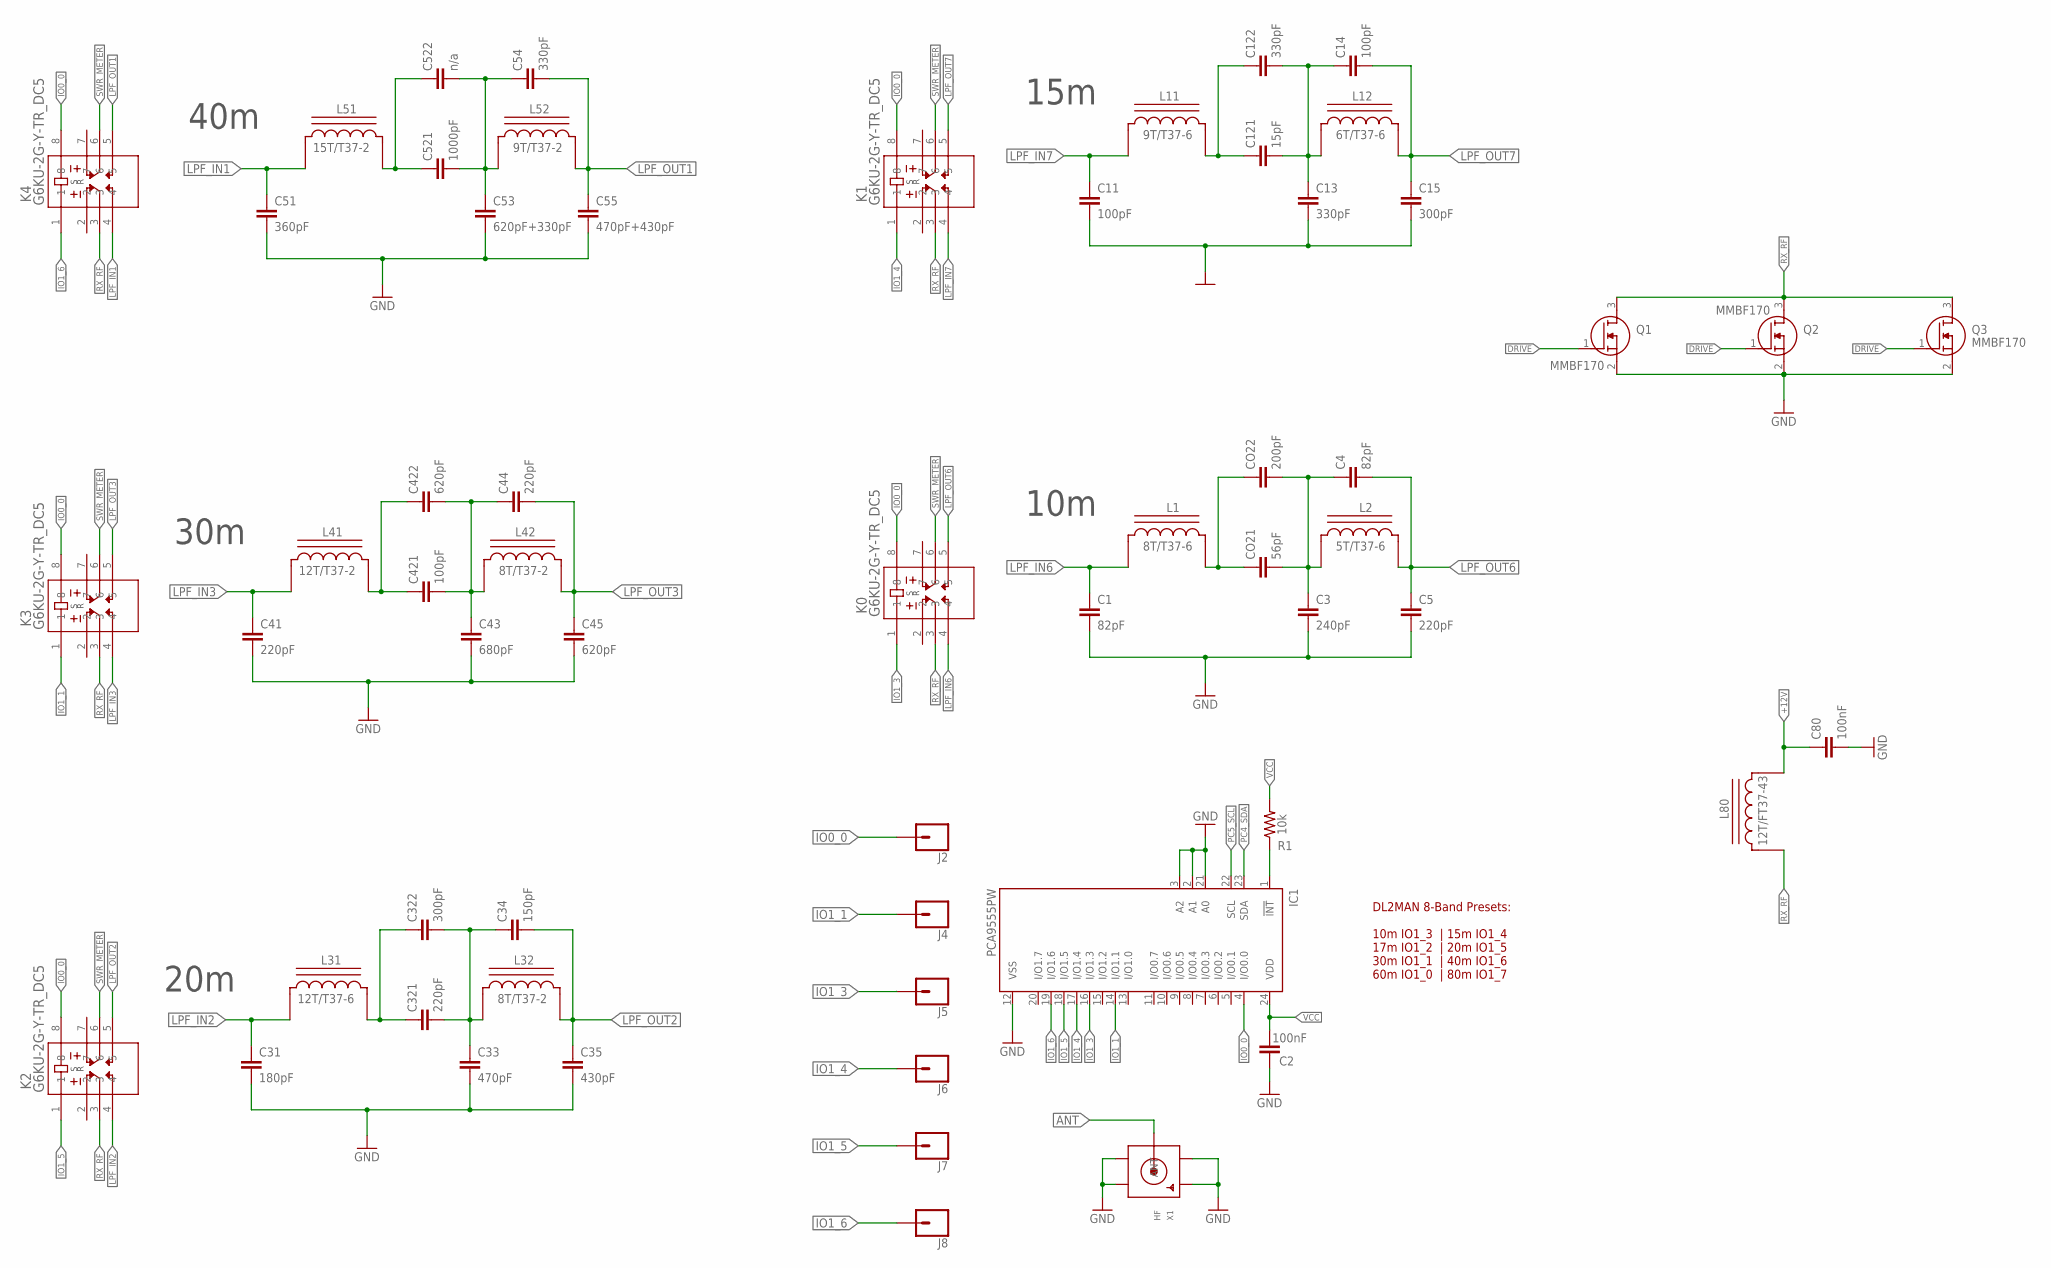
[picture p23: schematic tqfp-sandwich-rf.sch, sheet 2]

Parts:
C1, C4: 82pF; RESC0805_L
C2, C80: 100nF; RESC0805_L
C3: 240pF; RESC0805_L
C5, C41, C44, C321: 220pF; RESC0805_L
C11, C14, C421: 100pF; RESC0805_L
C13, C54, C122: 330pF; RESC0805_L
C15, C322: 300pF; RESC0805_L
C31: 180pF; RESC0805_L
C33: 470pF; RESC0805_L
C34: 150pF; RESC0805_L
C35: 430pF; RESC0805_L
C43: 680pF; RESC0805_L
C45, C422: 620pF; RESC0805_L
C51: 360pF; RESC0805_L
C53: 620pF+330pF; RESC0805_L
C55: 470pF+430pF; RESC0805_L
C121: 15pF; RESC0805_L
C521: 1000pF; RESC0805_L
C522: n/a; RESC0805_L
CO21: 56pF; RESC0805_L
CO22: 200pF; RESC0805_L
IC1: PCA9555PW; TSSOP24
J2, J4, J5, J6, J7, J8: CONN_01OFFSET; 1X01_OFFSET
K0, K1, K2, K3, K4: G6KU-2G-Y-TR_DC5; G6KU-2G-Y_DC3_OMR
L1: 8T/T37-6; T37_INDUCTOR
L2: 5T/T37-6; T37_INDUCTOR
L11: 9T/T37-6; T37_INDUCTOR
L12: 6T/T37-6; T37_INDUCTOR
L31: 12T/T37-6; T37_INDUCTOR
L32, L42: 8T/T37-2; T37_INDUCTOR
L41: 12T/T37-2; T37_INDUCTOR
L51: 15T/T37-2; T37_INDUCTOR
L52: 9T/T37-2; T37_INDUCTOR
L80: 12T/FT37-43; T37_INDUCTOR
Q1, Q2, Q3: MMBF170; SOT96P237X111-3N
R1: 10k; 0603
X1: HF; SMA_EDGELAUNCH

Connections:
+12V: C80.1, L80.CA; also elsewhere on the board
ANT: X1.P (ANT); also elsewhere on the board
DRIVE: Q1.1 (G), Q2.1 (G), Q3.1 (G); also elsewhere on the board
GND: C1.2, C2.1, C3.2, C5.2, C11.2, C13.2, C15.2, C31.2, C33.2, C35.2, C41.2, C43.2, C45.2, C51.2, C53.2, C55.2, C80.2, IC1.2 (A1), IC1.3 (A2), IC1.12 (VSS), IC1.21 (A0), Q1.2 (S), Q2.2 (S), Q3.2 (S), X1.GND@1 (GND4), X1.GND@2 (GND3), X1.GND@3 (GND2), X1.GND@4 (GND1); also elsewhere on the board
IO0_0: IC1.4 (I/O0.0), J2.1, K0.8, K1.8, K2.8, K3.8, K4.8
IO1_1: IC1.14 (I/O1.1), J4.1, K3.1
IO1_3: IC1.16 (I/O1.3), J5.1, K0.1
IO1_4: IC1.17 (I/O1.4), J6.1, K1.1
IO1_5: IC1.18 (I/O1.5), J7.1, K2.1
IO1_6: IC1.19 (I/O1.6), J8.1, K4.1
LPF_IN1: C51.1, K4.4, L51.CB
LPF_IN2: C31.1, K2.4, L31.CB
LPF_IN3: C41.1, K3.4, L41.CB
LPF_IN6: C1.1, K0.4, L1.CB
LPF_IN7: C11.1, K1.4, L11.CB
LPF_OUT1: C54.2, C55.1, K4.5, L52.CA
LPF_OUT2: C34.2, C35.1, K2.5, L32.CA
LPF_OUT3: C44.2, C45.1, K3.5, L42.CA
LPF_OUT6: C4.2, C5.1, K0.5, L2.CA
LPF_OUT7: C14.2, C15.1, K1.5, L12.CA
unnamed: CO21.1, CO22.1, L1.CA
unnamed: C3.1, C4.1, CO21.2, CO22.2, L2.CB
unnamed: C121.1, C122.1, L11.CA
unnamed: C13.1, C14.1, C121.2, C122.2, L12.CB
unnamed: IC1.1 (!INT), R1.1
unnamed: C421.1, C422.1, L41.CA
unnamed: C43.1, C44.1, C421.2, C422.2, L42.CB
unnamed: C321.1, C322.1, L31.CA
unnamed: C33.1, C34.1, C321.2, C322.2, L32.CB
unnamed: C521.1, C522.1, L51.CA
unnamed: C53.1, C54.1, C521.2, C522.2, L52.CB
PC4_SDA: IC1.23 (SDA); also elsewhere on the board
PC5_SCL: IC1.22 (SCL); also elsewhere on the board
RX_RF: K0.3, K1.3, K2.3, K3.3, K4.3, L80.CB, Q1.3 (D), Q2.3 (D), Q3.3 (D); also elsewhere on the board
SWR_METER: K0.6, K1.6, K2.6, K3.6, K4.6; also elsewhere on the board
VCC: C2.2, IC1.24 (VDD), R1.2; also elsewhere on the board

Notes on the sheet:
20m
40m
30m
10m
15m
DL2MAN 8-Band Presets: 10m IO1_3 | 15m IO1_4 17m IO1_2 | 20m IO1_5 30m IO1_1 | 40m IO1_6 60m IO1_0 | 80m IO1_7

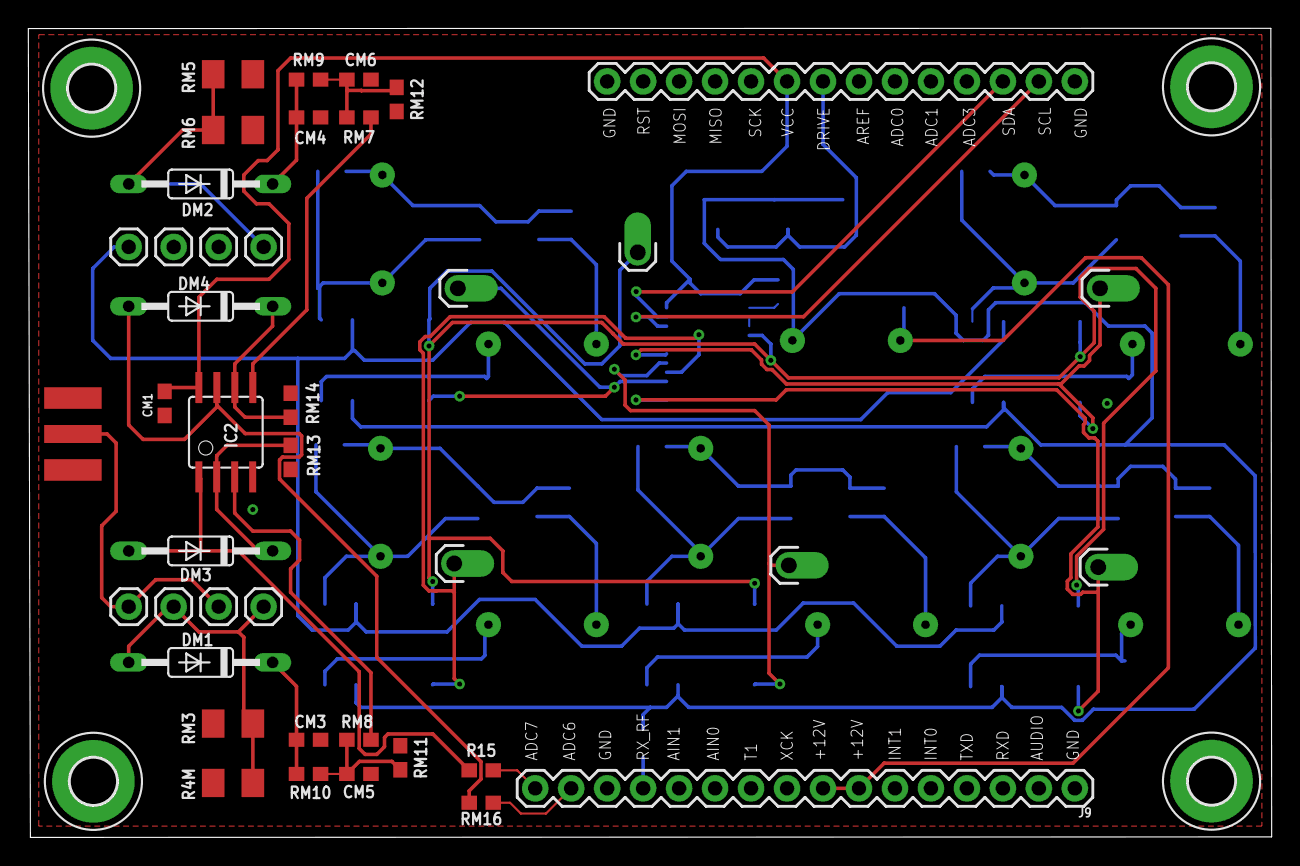
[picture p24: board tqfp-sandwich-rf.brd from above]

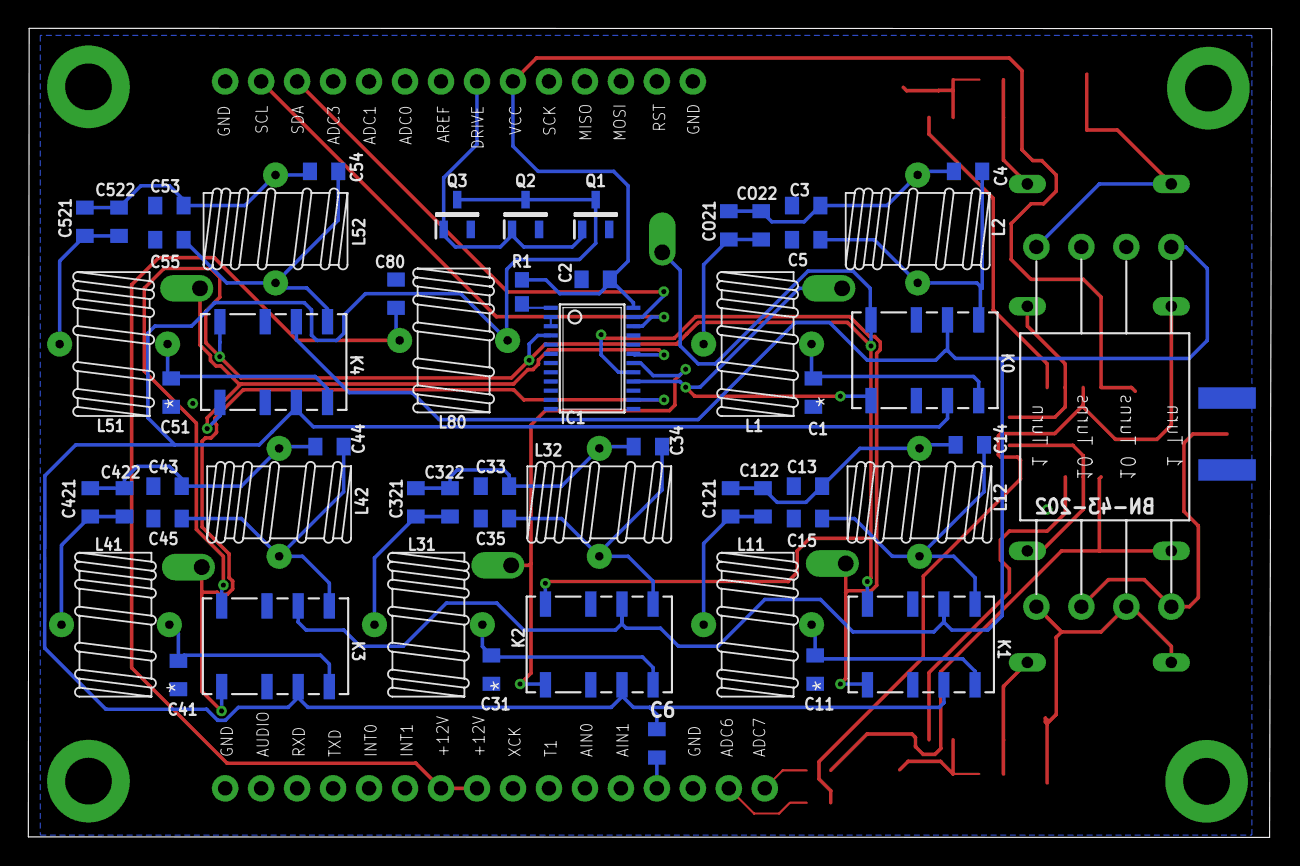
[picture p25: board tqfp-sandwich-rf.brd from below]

Board: 2 copper layers, 87.8 x 57.1 mm, 99 parts (54 on the bottom side), 51 nets.

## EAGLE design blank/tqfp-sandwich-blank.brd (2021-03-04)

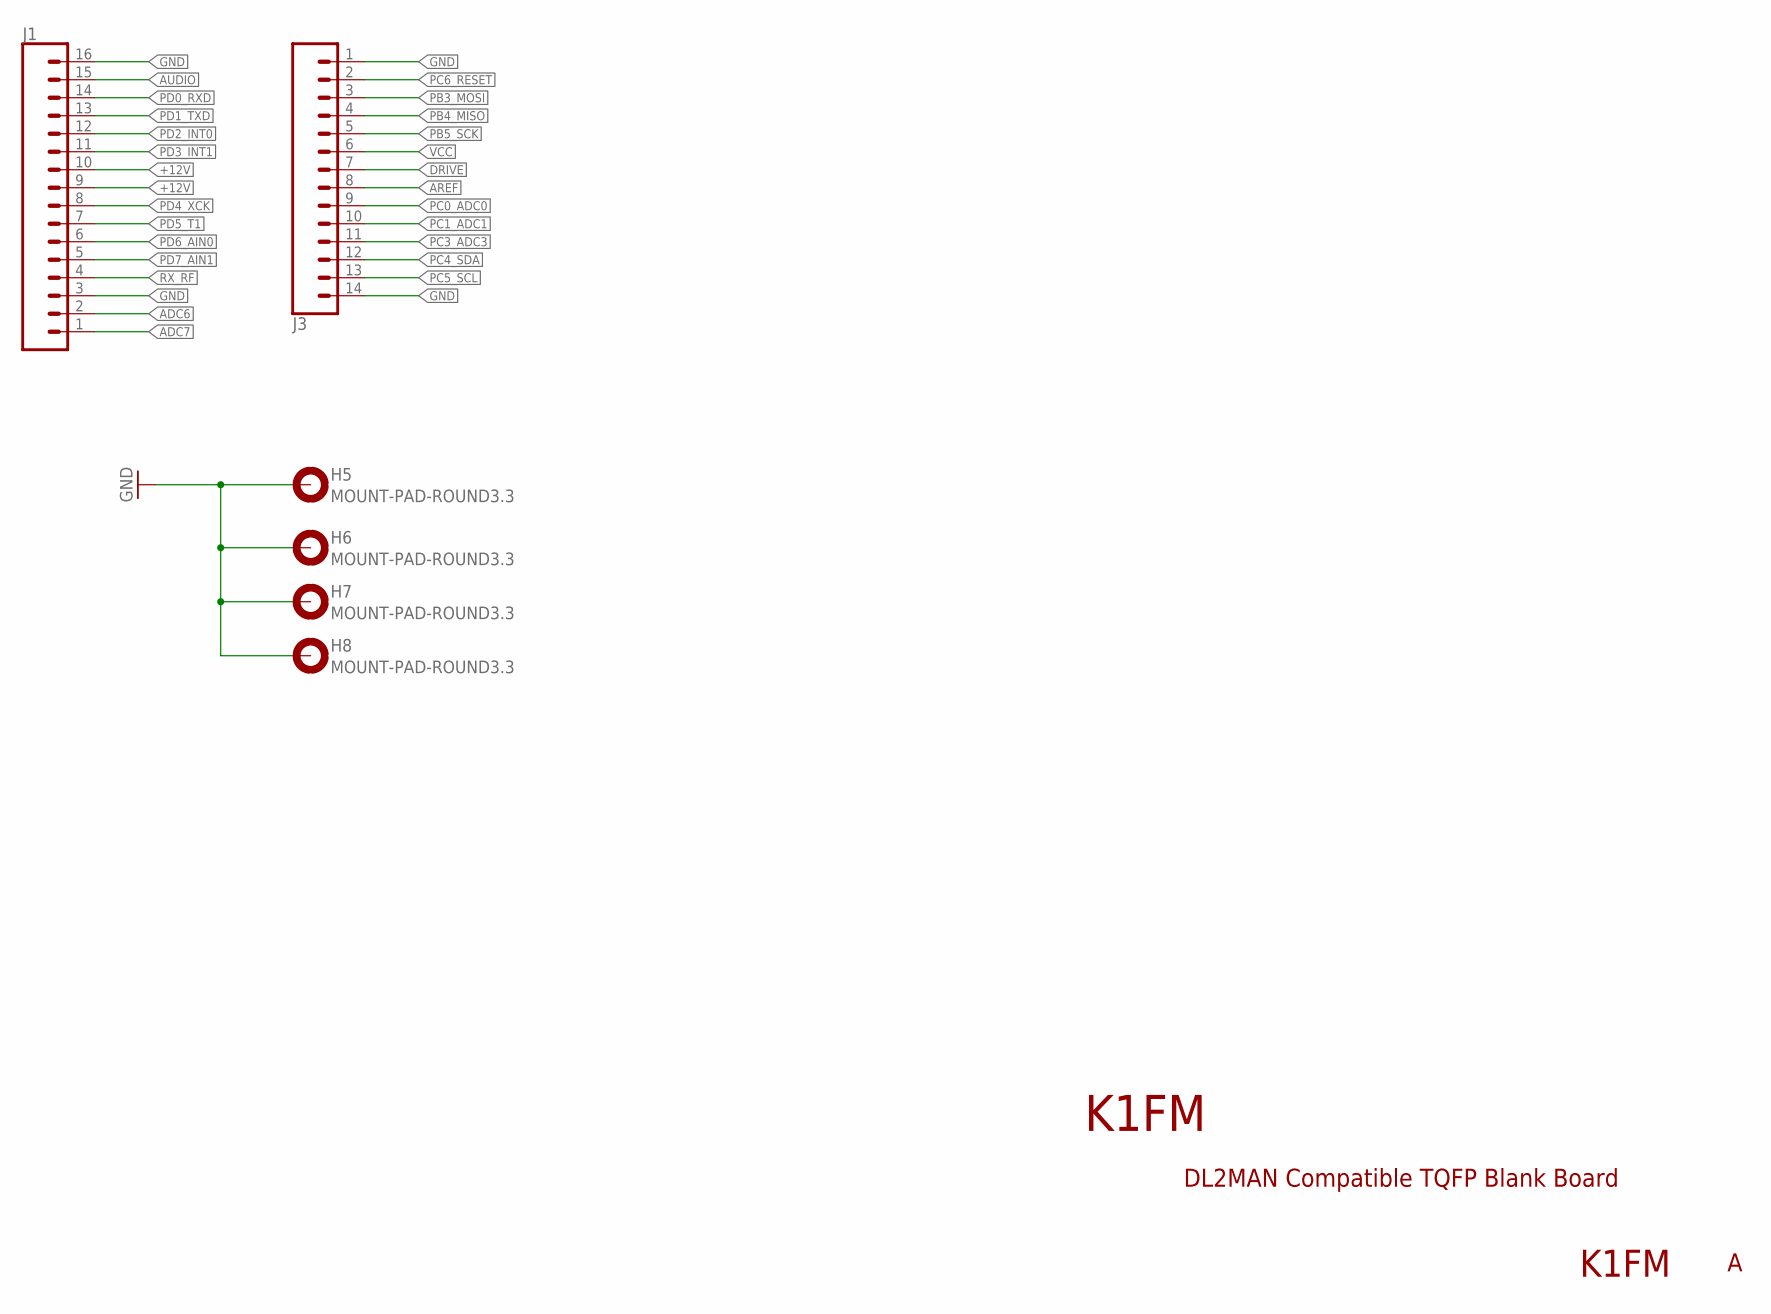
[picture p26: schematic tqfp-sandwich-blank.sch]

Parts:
H5, H6, H7, H8: MOUNT-PAD-ROUND3.3; 3,3-PAD
J1: CONN_16; 1X16
J3: CONN_14; 1X14

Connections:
+12V: J1.9, J1.10
ADC6: J1.2
ADC7: J1.1
AREF: J3.8
AUDIO: J1.15
DRIVE: J3.7
GND: H5.B3,3, H6.B3,3, H7.B3,3, H8.B3,3, J1.3, J1.16, J3.1, J3.14
PB3_MOSI: J3.3
PB4_MISO: J3.4
PB5_SCK: J3.5
PC0_ADC0: J3.9
PC1_ADC1: J3.10
PC3_ADC3: J3.11
PC4_SDA: J3.12
PC5_SCL: J3.13
PC6_RESET: J3.2
PD0_RXD: J1.14
PD1_TXD: J1.13
PD2_INT0: J1.12
PD3_INT1: J1.11
PD4_XCK: J1.8
PD5_T1: J1.7
PD6_AIN0: J1.6
PD7_AIN1: J1.5
RX_RF: J1.4
VCC: J3.6

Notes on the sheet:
DL2MAN Compatible TQFP Blank Board
K1FM

Board: 2 copper layers, 6 parts (0 on the bottom side), 2 nets, no tracks yet.

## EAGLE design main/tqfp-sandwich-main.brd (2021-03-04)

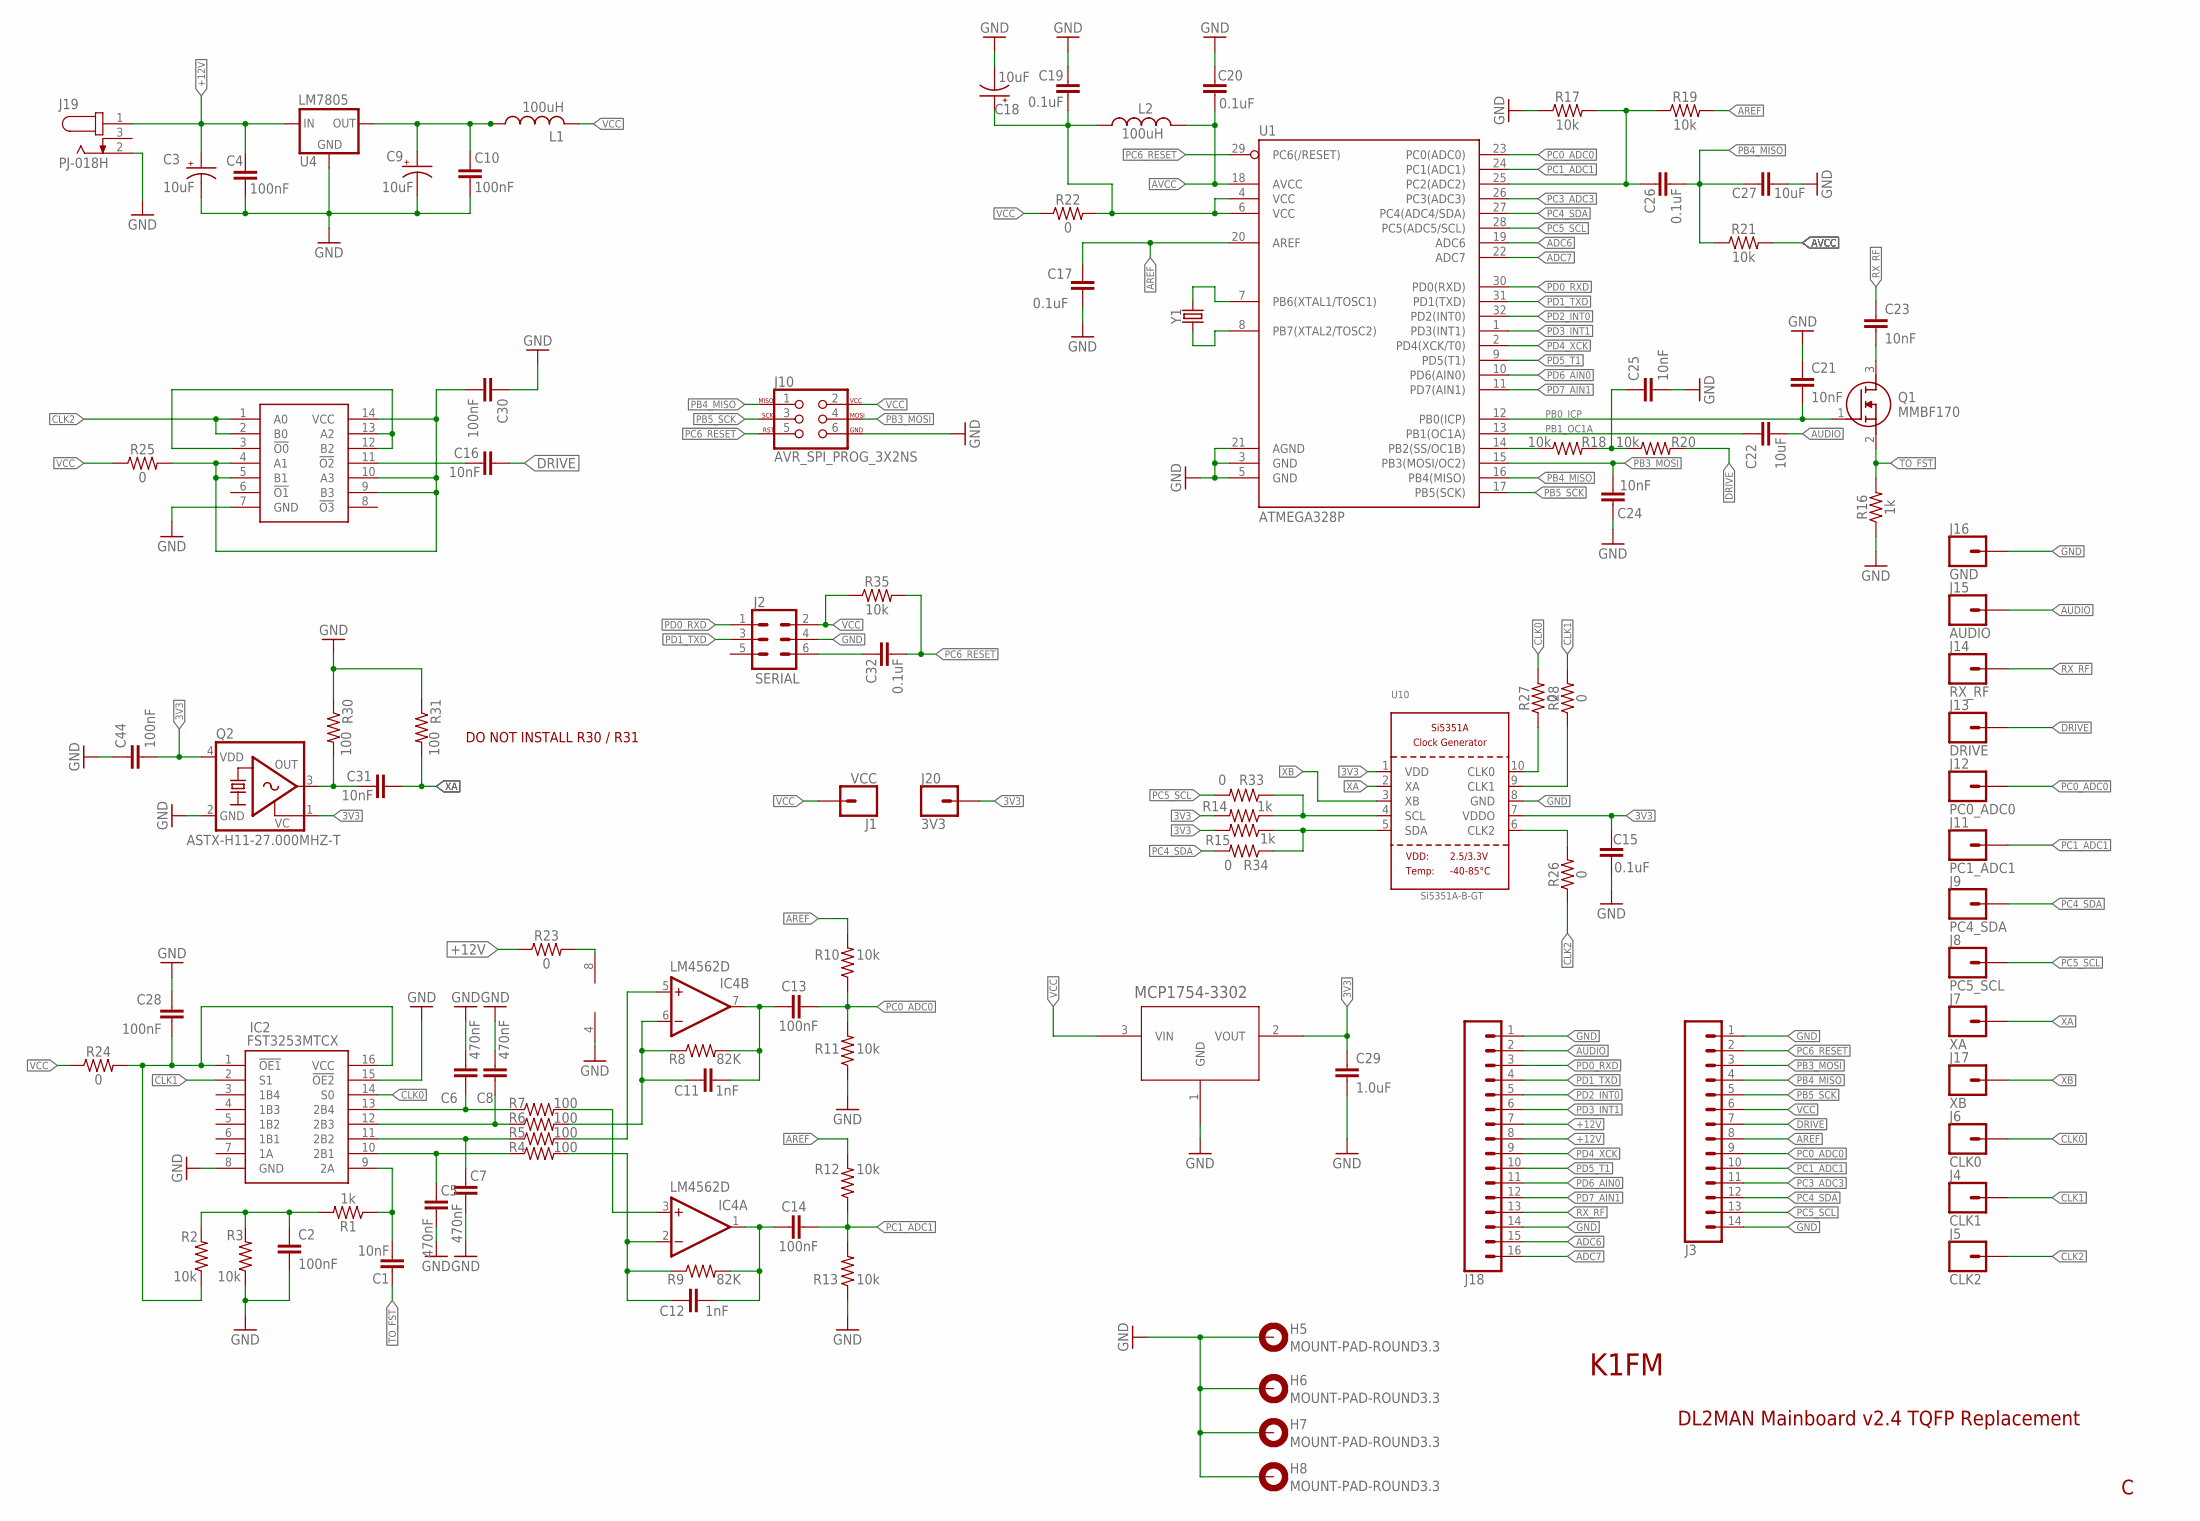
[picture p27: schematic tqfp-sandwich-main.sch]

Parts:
C1, C16, C21, C23, C24, C25, C31: 10nF; 0603
C2, C4, C10, C13, C14, C28, C30, C44: 100nF; 0603
C3, C9, C18: 10uF; EIA3216
C5, C6, C7, C8: 470nF; 0603
C11, C12: 1nF; 0603
C15, C17, C19, C20, C26, C32: 0.1uF; 0603
C22, C27: 10uF; 0603
C29: 1.0uF; 0603
H5, H6, H7, H8: MOUNT-PAD-ROUND3.3; 3,3-PAD
IC2: FST3253MTCX; SOP65P640X110-16N
IC3: 74ACT00MTC; SOP65P640X120-14N
IC4: LM4562D; SO08
J1: VCC; 1X01NS_KIT
J2: SERIAL; 2X3
J3: CONN_14; 1X14
J4: CLK1; 1X01_LONGPAD
J5: CLK2; 1X01_LONGPAD
J6: CLK0; 1X01_LONGPAD
J7: XA; 1X01_LONGPAD
J8: PC5_SCL; 1X01_LONGPAD
J9: PC4_SDA; 1X01_LONGPAD
J10: AVR_SPI_PROG_3X2NS; 2X3-NS
J11: PC1_ADC1; 1X01_LONGPAD
J12: PC0_ADC0; 1X01_LONGPAD
J13: DRIVE; 1X01_LONGPAD
J14: RX_RF; 1X01_LONGPAD
J15: AUDIO; 1X01_LONGPAD
J16: GND; 1X01_LONGPAD
J17: XB; 1X01_LONGPAD
J18: CONN_16; 1X16
J19: PJ-018H; CUI_PJ-018H
J20: 3V3; 1X01NS_KIT
L1, L2: 100uH; RESC0805_L
Q1: MMBF170; SOT96P237X111-3N
Q2: ASTX-H11-27.000MHZ-T; 3.2X2.5_KXO-84
R1, R14, R15, R16: 1k; 0603
R2, R3, R10, R11, R12, R13, R17, R18, R19, R20, R21, R35: 10k; 0603
R4, R5, R6, R7, R30, R31: 100; 0603
R8, R9: 82K; 0603
R22, R23, R24, R25, R26, R27, R28, R33, R34: 0; 0603
U1: ATMEGA328P; TQFP32-08
U3: MCP1754X-XXXXX/C; SOT-23A_MC
U4: LM7805; TO-252
U10: Si5351A-B-GT; MSOP10
Y1: CRYSTALSMD-5X3.2-2PAD; CRYSTAL-SMD-5X3.2-2PAD

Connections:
3V3: C15.2, C29.1, C44.2, J20.1, Q2.1 (VC), Q2.4 (VDD), R14.2, R15.2, U3.2 (VOUT), U10.1 (VDD), U10.7 (VDDO)
5V1: C9.+, C10.2, L1.1, U4.2 (OUT)
+12V: C3.+, C4.2, J18.7, J18.8, J19.1, R23.1, U4.1 (IN)
ADC6: J18.15, U1.19 (ADC6)
ADC7: J18.16, U1.22 (ADC7)
AREF: C17.2, J3.8, R10.2, R12.2, R19.2, U1.20 (AREF)
AUDIO: C22.2, J15.1, J18.2
AVCC: C20.1, L2.2, R21.2, U1.18 (AVCC)
CLK0: IC2.14 (S0), J6.1, R27.2
CLK1: IC2.2 (S1), J4.1, R28.2
CLK2: IC3.1 (A0), IC3.2 (B0), J5.1, R26.1
DRIVE: C16.2, J3.7, J13.1, R20.2
GND: C2.2, C3.-, C4.1, C5.2, C6.2, C7.2, C8.2, C9.-, C10.1, C15.1, C17.1, C18.-, C19.2, C20.2, C21.1, C24.1, C25.2, C27.2, C28.1, C29.2, C30.1, C44.1, H5.B3,3, H6.B3,3, H7.B3,3, H8.B3,3, IC2.8 (GND), IC2.15 (!OE2), IC3.7 (GND), IC4.4 (V-), J2.4, J3.1, J3.14, J10.6, J16.1, J18.1, J18.14, J19.2, Q2.2 (GND), R3.1, R11.1, R13.1, R16.1, R17.1, R30.1, R31.1, U1.3 (GND), U1.5 (GND), U1.21 (AGND), U3.1 (GND), U4.3 (GND), U10.8 (GND)
unnamed: U1.7 (PB6(XTAL1/TOSC1)), Y1.P$2 (2)
unnamed: U1.8 (PB7(XTAL2/TOSC2)), Y1.P$1 (1)
unnamed: C23.2, Q1.3 (D)
unnamed: C26.2, R17.2, R19.1, U1.25 (PC2(ADC2))
unnamed: IC3.3 (!O0), IC3.12 (B2), IC3.13 (A2)
unnamed: R18.1, U1.14 (PB2(SS/OC1B))
unnamed: C25.1, R18.2, R20.1
unnamed: C31.1, Q2.3 (OUT), R30.2
unnamed: C5.1, IC2.10 (2B1), R4.1
unnamed: C16.1, IC3.11 (!O2)
unnamed: C18.+, C19.1, L2.1, R22.2, U1.4 (VCC), U1.6 (VCC)
unnamed: C1.2, IC2.9 (2A), R1.1
unnamed: C2.1, R1.2, R2.2, R3.2
unnamed: C7.1, IC2.11 (2B2), R5.1
unnamed: C8.1, IC2.12 (2B3), R6.1
unnamed: C6.1, IC2.13 (2B4), R7.1
unnamed: IC4.5 (+IN), R5.2
unnamed: C12.1, IC4.2 (-IN), R4.2, R9.1
unnamed: C11.1, IC4.6 (-IN), R6.2, R8.1
unnamed: IC4.3 (+IN), R7.2
unnamed: C11.2, C13.1, IC4.7 (OUT), R8.2
unnamed: C12.2, C14.1, IC4.1 (OUT), R9.2
unnamed: IC4.8 (V+), R23.2
unnamed: C28.2, IC2.1 (!OE1), IC2.16 (VCC), R2.1, R24.2
unnamed: C30.2, IC3.4 (A1), IC3.5 (B1), IC3.9 (B3), IC3.10 (A3), IC3.14 (VCC), R25.2
unnamed: R27.1, U10.10 (CLK0)
unnamed: R28.1, U10.9 (CLK1)
unnamed: R26.2, U10.6 (CLK2)
unnamed: R14.1, R33.1, U10.4 (SCL)
unnamed: R15.1, R34.1, U10.5 (SDA)
unnamed: C32.2, J2.6
PB0_ICP: C21.2, Q1.1 (G), U1.12 (PB0(ICP))
PB1_OC1A: C22.1, U1.13 (PB1(OC1A))
PB3_MOSI: C24.2, J3.3, J10.4, U1.15 (PB3(MOSI/OC2))
PB4_MISO: C26.1, C27.1, J3.4, J10.1, R21.1, U1.16 (PB4(MISO))
PB5_SCK: J3.5, J10.3, U1.17 (PB5(SCK))
PC0_ADC0: C13.2, J3.9, J12.1, R10.1, R11.2, U1.23 (PC0(ADC0))
PC1_ADC1: C14.2, J3.10, J11.1, R12.1, R13.2, U1.24 (PC1(ADC1))
PC3_ADC3: J3.11, U1.26 (PC3(ADC3))
PC4_SDA: J3.12, J9.1, R34.2, U1.27 (PC4(ADC4/SDA))
PC5_SCL: J3.13, J8.1, R33.2, U1.28 (PC5(ADC5/SCL))
PC6_RESET: C32.1, J3.2, J10.5, R35.2, U1.29 (PC6(/RESET))
PD0_RXD: J2.1, J18.3, U1.30 (PD0(RXD))
PD1_TXD: J2.3, J18.4, U1.31 (PD1(TXD))
PD2_INT0: J18.5, U1.32 (PD2(INT0))
PD3_INT1: J18.6, U1.1 (PD3(INT1))
PD4_XCK: J18.9, U1.2 (PD4(XCK/T0))
PD5_T1: J18.10, U1.9 (PD5(T1))
PD6_AIN0: J18.11, U1.10 (PD6(AIN0))
PD7_AIN1: J18.12, U1.11 (PD7(AIN1))
RX_RF: C23.1, J14.1, J18.13
TO_FST: C1.1, Q1.2 (S), R16.2
VCC: J1.1, J2.2, J3.6, J10.2, L1.2, R22.1, R24.1, R25.1, R35.1, U3.3 (VIN)
XA: C31.2, J7.1, R31.2, U10.2 (XA)
XB: J17.1, U10.3 (XB)

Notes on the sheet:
DL2MAN Mainboard v2.4 TQFP Replacement
K1FM
DO NOT INSTALL R30 / R31

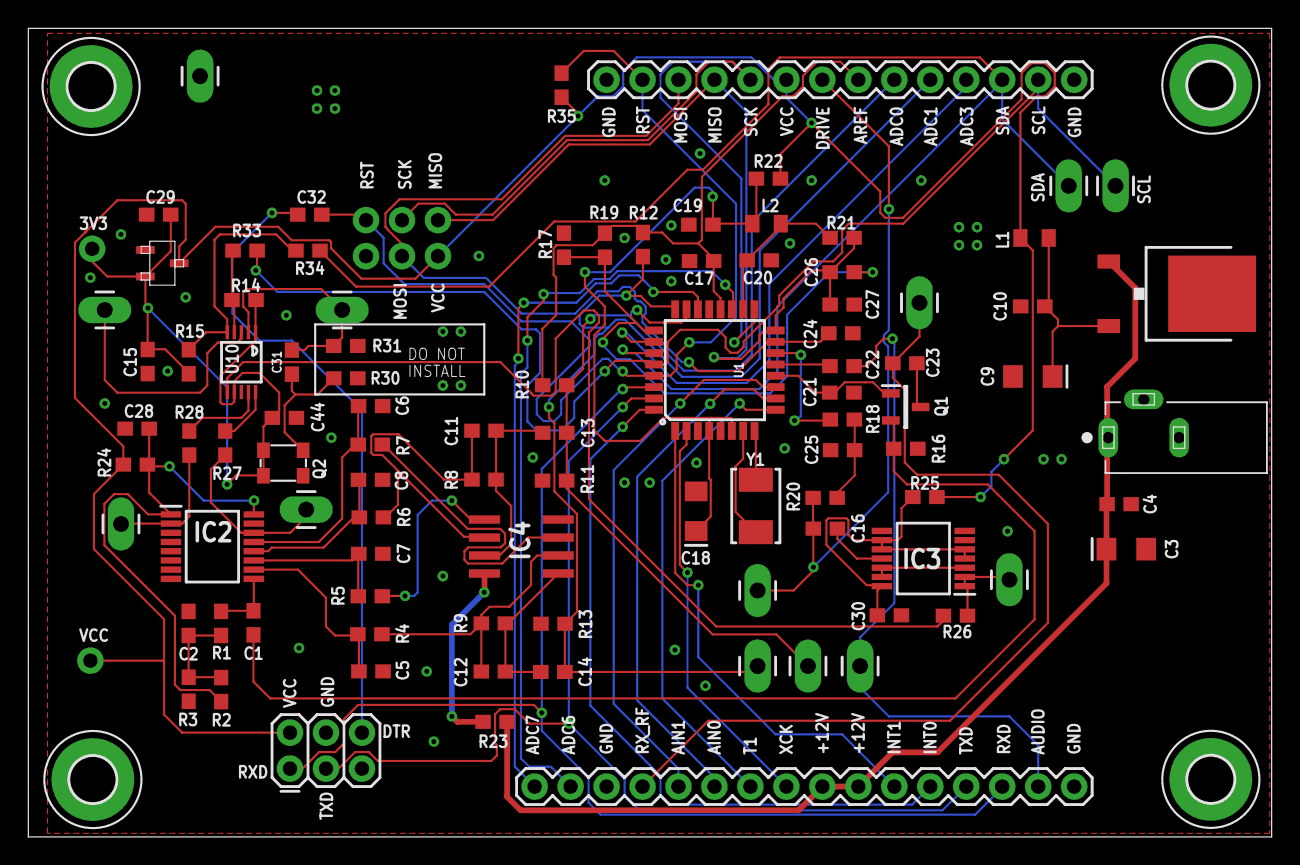
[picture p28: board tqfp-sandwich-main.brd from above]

Board: 2 copper layers, 87.8 x 57.1 mm, 102 parts (0 on the bottom side), 68 nets.

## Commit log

2020-12-24 Fix C18 polarization on the shematic
    BOM Used a non-polarized capacitor, so the comment was changed
    [tqfp-sandwitch-bom_2020-12-11.csv]
2021-03-01 Fix C5 C6 C7 C8 BOM part number / value
    [tqfp-sandwitch-bom_2020-12-11.csv]
2021-03-01 Add source drawings
    [tqfp-sandwich.brd, tqfp-sandwich.sch]
2021-03-04 Add main, ui, rf, enclosure, blank
    [antenna-side.stl, base.stl, bottom.stl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]
2021-03-04 Remove old schematics
    [tqfp-sandwich.brd, tqfp-sandwich.sch]
2021-03-05 Rename gerber files
2021-03-06 Add capacitor on the MCP6002 power rail
    [tqfp-sandwich-rf.brd, tqfp-sandwich-rf.sch]
2021-03-08 Remove mosfets, inductors, capacitors values.
    The board can accept two different kind of finals (MMBF170 or IRLML2060).
    Capacitors and inductors need to follow this choice therefore they
    probably shouldn't be explicitly indicated on the schematic.
    [tqfp-sandwich-rf.sch]
2021-03-18 GPS fix, Add LM386 (thanks Kris SQ3PCA)
    [tqfp-sandwich-ui.brd, tqfp-sandwich-ui.sch]
2021-06-10 Removed old gerber file
2021-11-20 Main board BOM corrections (tnx Janez S58J)
    [tqfp-sandwich-bom_2021-03-03.csv]

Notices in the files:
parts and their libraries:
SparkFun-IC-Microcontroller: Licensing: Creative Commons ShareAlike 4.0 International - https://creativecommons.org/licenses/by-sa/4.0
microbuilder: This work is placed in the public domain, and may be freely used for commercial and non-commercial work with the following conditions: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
